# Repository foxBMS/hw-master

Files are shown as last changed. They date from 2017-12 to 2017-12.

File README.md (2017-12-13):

# foxBMS

foxBMS is a free, open and flexible development environment to design battery management systems. It is the first modular open source BMS development platform.

## foxBMS Project Setup
The foxBMS project consists of several repositories.

The foxConda environment. This environment provides all the tools necessary to generate the documentation, compile the code for the MCUs and flash the generated binaries on the MCUs (e.g., Python, git, GCC).

The starting point to get foxBMS is the foxBMS-setup repository (https://github.com/foxBMS/foxbms-setup), which contains the general setup files for the foxBMS project. It includes a setup script (bootstrap.py) which clones all the other needed repositories. The needed documentation will be generated automatically after these repositories have been cloned. The generated documentation is found in the directory ./build. After the bootstrap step, the top project directory (foxBMS-setup) structure looks like this:

 - foxbms-setup <dir>
  - .git <dir> *
  - build <dir>
  - documentation <dir>
  - embedded-software
   - mcu-primary <dir>
   - mcu-secondary <dir>
   - mcu-common <dir>
   - mcu-freertos <dir>
   - mcu-hal <dir>
  - tools <dir>
  - .gitignore <file> *
  - .config.yaml <file> *
  - bootstrap.py <file>
  - build.py <file>
  - CHANGELOG.md <file>
  - LICENSE.md <file>
  - README.md <file>
  - wscript <file>

* Directories and files with starting full stop are hidden in Windows in default configuration. 

There is a help available by running "python bootstrap.py -h".

## foxBMS Repositories

The foxbms-setup repositories have already been described.

foxBMS is made out of two Microcontroller Units (MCU), named primary and secondary. The C code for the primary MCU is found in the repository foxBMS-primary (https://github.com/foxBMS/mcu-primary). The C code for the secondary MCU is found in the repository foxBMS-secondary (https://github.com/foxBMS/mcu-secondary). The C code common to the primary and secondary MCU is found in the repository mcu-common (https://github.com/foxBMS/mcu-common).The Doxygen documentation is generated from these sources into ./build/primary/doxygen/html and ./build/secondary/doxygen/html respectively. The main file is in both cases index.html.

The layout and schematic files for the foxBMS hardware are found in the foxBMS-hardware repository (https://github.com/foxBMS/hardware).

The Hardware Abstraction Layer (hal) for foxBMS is found in the hal-repository (https://github.com/foxBMS/mcu-hal). The real time operating system (FreeRTOS) for foxBMS is found in the FreeRTOS-repository (https://github.com/foxBMS/mcu-freertos).

The tools needed for foxBMS are in the foxBMS-tools-repository (https://github.com/foxBMS/tools.)

The general documentation files for the foxBMS project are found in the foxBMS-documentation repository (https://github.com/foxBMS/documentation). The sphinx documentation is found in foxBMS-documentation/doc/sphinx while the Doxygen documentation configuration is found in foxBMS-documentation/doc/doxygen. The Doxygen documentation itself is found in the software sources of the primary and secondary microcontroller. The general documentation, rendered from the sphinx sources is found in ./build/sphinx/foxBMS-documentation/doc/sphinx/html. The main file is index.html

A generated version of the Sphinx documentation can be found at http://foxbms.readthedocs.io/. It explains the structure of the foxBMS hardware, how to install the foxConda environment and how to use foxConda to compile and flash the sources.

## Building the Sources
For building the software, open a shell and type "python build.py -h". All available build options will be displayed. The top build directory is ./build.

## Cleaning the ./build-Directory
For cleaning instructions open a shell and type "python clean.py -h". All available cleaning options will be displayed.

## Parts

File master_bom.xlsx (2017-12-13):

 | Pos | Populate | Qty | Value | Device | Package | Parts | Description | Farnell | Digikey | Mouser
Resistor
 | 1 | yes | 9 | 0 | R-EU_R0603 | R0603 | R403 R406 R501 R506 R705 R1403 R1404 R1407 R1408 | RESISTOR, European symbol | 2059527
 | 2 | yes | 2 | 1.5k | R-EU_R0603 | R0603 | R701 R702 | RESISTOR, European symbol | 2303156
 | 3 | yes | 12 | 10 | R-EU_R0603 | R0603 | R706 R901 R905 R909 R912 R1001 R1002 R1007 R1008 R1013 R1014 R806 | RESISTOR, European symbol | 2302958
 | 4 | yes | 32 | 10k | R-EU_R0603 | R0603 | R401 R402 R405 R407 R502 R504 R505 R507 R707 R708 R709 R710 R903 R904 R908 R911 R1003 R1004 R1009 R1010 R1015 R1016 R1107 R1108 R1109 R1110 R1111 R1112 R1501 R1502 R803 R805 | RESISTOR, European symbol | 2303192
 | 5 | yes | 1 | 120 | R-EU_R0603 | R0603 | R902 | RESISTOR, European symbol | 2303067
 | 6 | yes | 6 | 130 | R-EU_R0603 | R0603 | R201 R301 R408 R409 R508 R509 | RESISTOR, European symbol | 2059288
 | 7 | yes | 8 | 430 | R-EU_R0603 | R0603 | R907 R910 R1005 R1006 R1011 R1012 R1017 R1018 R804 | RESISTOR, European symbol | 2145386
 | 8 | yes | 1 | 330 | R-EU_R0603 | R0603 | R906 | RESISTOR, European symbol | 2145370
 | 9 | yes | 4 | 27 | R-EU_R0603 | R0603 | R1401 R1402 R1405 R1406 | RESISTOR, European symbol | 2145363
 | 10 | yes | 6 | 47 | R-EU_R0603 | R0603 | R1101 R1102 R1103 R1104 R1105 R1106 | RESISTOR, European symbol | 2145397
 | 11 | yes | 2 | 62 | R-EU_R0603 | R0603 | R801 R802 | RESISTOR, European symbol | 2303039
 | 12 | yes | 4 | 680 | R-EU_R0603 | R0603 | R404 R503 R703 R704 | RESISTOR, European symbol | 2303131
Capacitor
 | 13 | yes | 74 | 100n | C-EUC0603 | C0603 | C202 C206 C208 C301 C306 C308 C401 C404 C405 C406 C407 C408 C409 C410 C411 C412 C413 C415 C416 C417 C418 C419 C420 C421 C422 C424 C425 C430 C502 C503 C504 C506 C507 C508 C509 C510 C513 C601 C602 C703 C706 C707 C1103 C1104 C1105 C1106 C1107 C1402 C1403 C1404 C1405 C1407 C1408 C1409 C1410 C1601 C1602 C1603 C1604 C1801 C1802 C1803 C1804 C1805 C1806 C1807 C2101 C2102 C803 C804 C805 C806 C807 C1501 | CAPACITOR, European symbol | 1828890
 | 14 | yes | 4 | 100n 50V | C-EUC0604 | C0603 | C702 C802 C902 C1102 | CAPACITOR, European symbol | 2346967
 | 15 | yes | 8 | 18p | C-EUC0605 | C0603 | C402 C414 C428 C429 C501 C505 C704 C705 | CAPACITOR, European symbol | 2070403
 | 16 | yes | 6 | 1µ | C-EUC0606 | C0603 | C205 C207 C305 C307 C403 C423 | CAPACITOR, European symbol | 1907343
 | 17 | yes | 3 | 1µ 35V | C-EUC0607 | C0603 | C701 C801 C1101 | CAPACITOR, European symbol | 2346909
 | 18 | yes | 4 | 2.2µ | C-EUC0608 | C0603 | C426 C427 C511 C512 | CAPACITOR, European symbol | 2346961
 | 19 | yes | 7 | 2.2µ 50V | C-EUC0609 | C0805 | C201 C203 C204 C302 C303 C304 C901 | CAPACITOR, European symbol | 2346945
 | 20 | yes | 2 | 4.7µ | C-EUC0610 | C0603 | C1401 C1406 | CAPACITOR, European symbol | 2362098
L
 | 21 | yes | 1 |  | L0805 | 0805 | L401 |  | 2443249
 | 22 | yes | 1 |  | B82789N | B82789N | L801 |  |  |  | 871-B82789C513N2
LED
 | 23 | yes | 2 | Green | LEDCHIP-LED0603 | CHIP-LED0603 | LED402 LED502 | LED | 2099223
 | 24 | yes | 2 | Red | LEDCHIP-LED0603 | CHIP-LED0603 | LED401 LED501 | LED | 2099221
 | 25 | yes | 2 | Orange | LEDCHIP-LED0603 | CHIP-LED0603 | LED201 LED301 | LED | 2099222
XTAL
 | 26 | yes | 2 | 7B-8.000MAAJ-T | 7B-8.000MAAJ-T | MJ | Q401 Q501 | MJ Quarz, 5 x 3.2 x 1.0mm SMD | 2308726
 | 27 | yes | 1 |  | MS3V | MS3V-T1R | Q402 |  | 1539368
Transistor
 | 28 | yes | 2 | BSS84P | BSS84P | SOT23 | T401 T501 | #2245 | 1056526
 | 29 | yes | 1 | BUK964R8-60E | BUK964R8-60E | TO-263AB | T901 | #2797 N-Channel PowerTrench MOSFET 60V, 75A 10.5mOhm | 2254205
 | 30 | yes | 10 | IRLML0100TRPBF | IRLML0100TRPBF | SOT-23 | T701 T801 T902 T903 T1001 T1002 T1003 T1004 T1005 T1006 |  | 1783928
IC
 | 31 | yes | 1 | ADR3425 | ADR3425 | SOT23-6 | IC401 | Micropower, high accuracy, voltage references | 2377039
 | 32 | yes | 2 | ADUM3300 | ADUM3300 | SO-16W | IC1102 IC1103 | Triple-Channel Digital Isolators | 2409432
 | 33 | yes | 1 | ADUM3301 | ADUM3301 | SO-16W | IC702 | Triple-Channel Digital Isolators | 2462515
 | 34 | yes | 3 | ADUM3401 | ADUM3401 | SO16W | IC601 IC1403 IC1406 | Analog Devices Magnetkoppler 4-Kanal | 1274129
 | 35 | yes | 2 | FT231XS-R | FT231XS-R | IC_SMD_SSOP-20 | IC1402 IC1405 | FT231X?-* - FTDI | 2081328
 | 36 | yes | 1 | AT25128B-SSHL-T | AT25128B-SSHL-T | SO8 | IC1501 | SPI bus serial EEPROM | 2345601
 | 37 | yes | 1 | TJA1052IT/5Y | TJA1052IT/5Y | SO16W | IC802 |  | 2400552
Diode
 | 38 | yes | 1 | PESD1CAN | PESD1CAN | SOT-23_NEU | D801 | NXP PESD1CAN CAN bus ESD protection diode | 1510703
 | 39 | yes | 1 | STPS3L60U | STPS3L60U | SMB | D201 | Schottky Diode | 9907769
 | 40 | yes | 2 | MM3Z12VT1G | MM3Z12VT1G | SOD323 | D901 D902 | MM3Z_xVx_T1 Series Zener Diode | 1431191
 | 41 | yes | 6 | CDSOD323-T05 | CDSOD323-T05 | SOD323 | D1101 D1102 D1103 D1104 D1105 D1106 | TVS CDSOD323-T05 | 2341914
 | 42 | yes | 2 | MM3Z4V7ST1G | MM3Z4V7ST1G | SOD323 | D701 D702 | MM3Z_xVx_T1 Series Zener Diode | 2463512
 | 43 | no | 6 | GF1B | GF1B | SMA-DO214AC | D1001 D1002 D1003 D1004 D1005 D1006 | DIODE | 1467477
MCU
 | 44 | yes | 1 | STM32F429IIT6 | STM32F429IIT6 | LQFP176 | IC402 | ARM 32-bit Cortex™-M3 CPU |  | 497-14054-ND
 | 45 | yes | 1 | STM32F429VIT6 | STM32F429VGT6 | LQFP100 | IC501 | ARM 32-bit Cortex™-M3 CPU | 2393659
Regulator
 | 46 | yes | 1 | KA7805ERTF | KA7805ERTF | TO252 | IC801 | Positive VOLTAGE REGULATOR | 2102585
 | 47 | yes | 2 | UA78L05CPK | UA78L05CPK | SOT89 | IC701 IC1101 | POSITOIV-VOLTAGE REGULATORS | 2112604
 | 48 | yes | 2 | LM1085-3.3 | LM1085-3.3 | TO-263-3L | IC201 IC301 | National Semiconductor LM1085IS-5 3A Low Dropout Positive Regulators | 1469039
 | 49 | yes | 1 | LM317MSTT3 | LM317MSTT3 | SOT223 | IC901 | 500 mA Adjustable Output Positive Voltage Regulator | 1703412
Opto
 | 50 | yes | 6 | AQV252G2SX | AQV252G2SX | SOP06 | IC1001 IC1002 IC1003 IC1004 IC1005 IC1006 |  |  | 255-3594-1-ND
 | 51 | yes | 5 | CPC1008N | CPC1008N | SOP4 | IC803 IC902 IC903 IC904 IC905 | CLARE - Single-Pol, Normally Open 4-Pin SOP OptoMOS Relay, 150mA load current | 1653755
Misc
 | 52 | yes | 1 | SMTU 1225-1-LF | SMTU 1225-1-LF | CR1225_SMD | BATT | #2833 | 1216353
 | 53 | yes | 2 | MC32598 | MC32598 | Mini-USB AB | X1401 X1402 | MINI USB-B Conector | 1696539
 | 54 | yes | 2 | IP4220CZ6 | IP4220CZ6 | TSOP-6 | IC1401 IC1404 |  | 1506629
 | 55 | yes | 1 | IS42S16400J-7TLI | IS42S16400J-7TLI | TSOP-54 | IC1801 |  | 2253831
 | 56 | yes | 2 | KMR211G | KMR211G | KMR211G | S401 S501 | #228 |  | 401-1426-1-ND
 | 57 | yes | 6 | 4,0A_UMT | 4,0A_UMT | F_SMD_11,00MMX3,00MMX3,00MM_(UMT)_R_SCHURTER_REV01 | F1001 F1002 F1003 F1004 F1005 F1006 | UMT-Serie - Schurter Electronic Components |  | 486-1253-ND | 693-3403.0172.11
 | 58 | yes | 1 | 2A | Littelfuse 452 | NANO2 | F201 | 452 Serie Littelfuse | 2383284
 | 59 | yes | 1 | TISP4040H1BJR-S | TISP4040H1BJR-S | SMBJ | T201 | TVS Thyristor |  | TISP4040H1BJR-SCT-ND
Connector SMD
 | 60 | yes | 2 | FTS-110-01-L-DV | FTS-110-01-L-DV | FTS-110-01-L-DV | X403 X502 | SAMTEC connector, #537 | 1667733
Connector THD
 | 61 | yes | 1 | HEADER_POS16_43045-1599 | HEADER_POS16_43045-1600 | 43045-1600 | X1601 | Molex - Micro-Fit 3.0 Series connector, 3.00mm (0.118) pitch header, 16 positions." | 9961380
 | 62 | yes | 1 | HEADER_POS2_43045-0199 | HEADER_POS2_43045-0200 | 43045-0200 | X901 | Molex - Micro-Fit 3.0 Series connector, 3.00mm (0.118) pitch header, 2 positions." | 1012251
 | 63 | yes | 8 | HEADER_POS4_43045-0400 | HEADER_POS4_43045-0401 | 43045-0400 | X701 X801 X1201 X1202 X1203 X1204 X1205 X1206 | Molex - Micro-Fit 3.0 Series connector, 3.00mm (0.118) pitch header, 4 positions." | 9733019
 | 64 | yes | 1 | HEADER_POS6_43045-0599 | HEADER_POS6_43045-0600 | 43045-0600 | X201 | Molex - Micro-Fit 3.0 Series connector, 3.00mm (0.118) pitch header, 6 positions." | 1012252
 | 65 | yes | 1 | MA03-0 | MA03-1 | MA03-1 | X401 | 3Pins | 2505045
 | 66 | yes | 1 |  |  |  | SV901 | 8 Header | 1668094
 | 67 | yes | 3 | MA04-1 | MA04-2 | MA04-2 | SV1601 SV1603 SV2101 | 8 Pins | 2025250
 | 68 | yes | 1 | MA06-1 | MA06-2 | MA06-2 | SV501 | 12 Pins | 2025252
 | 69 | yes | 2 | MA08-1 | MA08-2 | MA08-2 | SV1602 SV1604 | 16 Pins | 2025254
 | 70 | no | 1 | MA02-0 | MA02-0 | MA02-0 | X902 | 1 Pins | 2505044
 | 71 | yes | 2 | MA02-1 | MA02-1 | MA02-1 | X402 X501 | 2 Pins | 2505044
 | 72 | yes | 2 | PINHD-2X11 | PINHD-2X12 | 2X12 | JP2201 JP2202 | 24 Header | 1804783 | SAM1088-12-ND
DC/DC THD
 | 73 | yes | 1 | MURATA_NCS6_SINGLE | MURATA_NCS6_SINGLE | NCS6S1205C | IC202 |  |  | 580-NCS6S1205C
 | 74 | yes | 1 | RECOM-RS2405SZ | RECOM-RS2405SZ | RS-2405SZ/H3 | IC302 |  |  | 919-RS-2405SZ/H3

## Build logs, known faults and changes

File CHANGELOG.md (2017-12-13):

# foxBMS Change Log

## V1.0.2

- replaced ADuM14XX isolators by ADuM34XX

## V1.0.1

- added fuse protection on power supply input

## V1.0.0

- initial release

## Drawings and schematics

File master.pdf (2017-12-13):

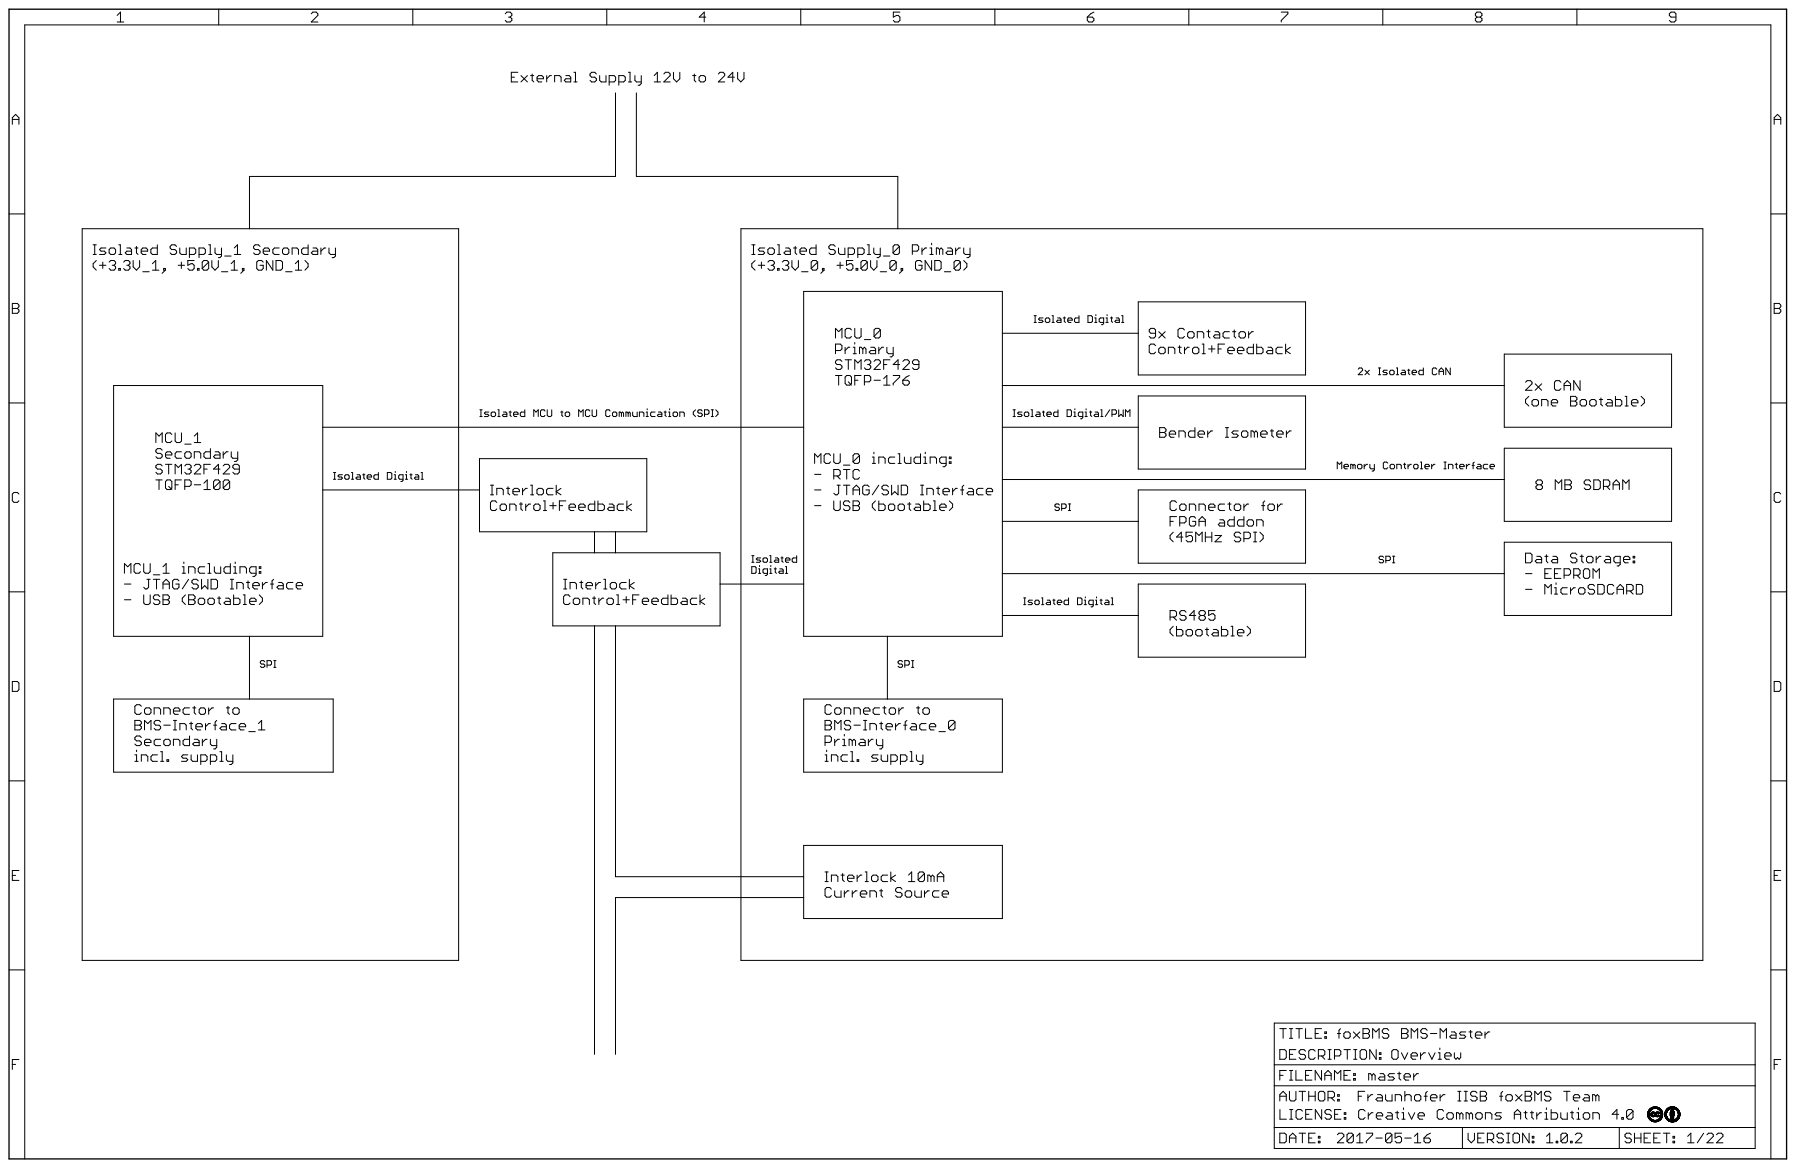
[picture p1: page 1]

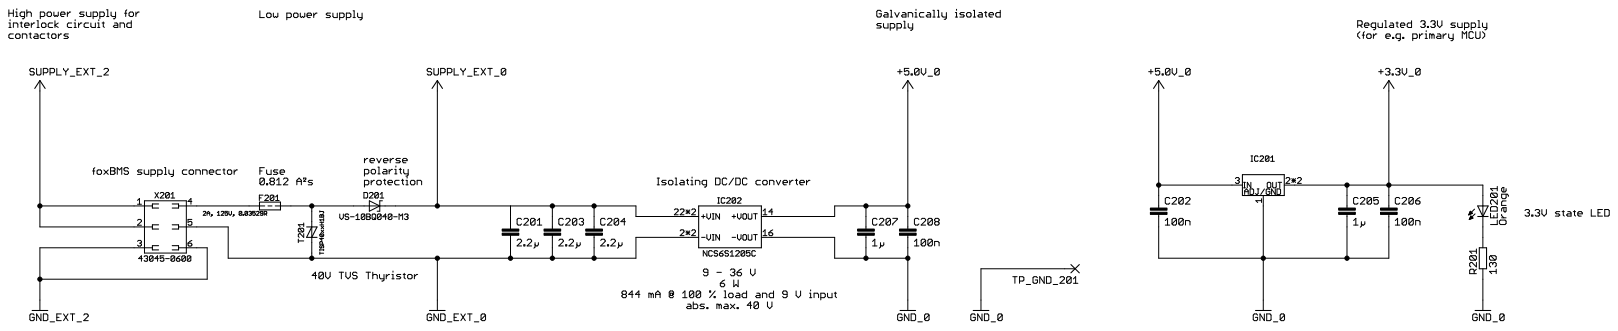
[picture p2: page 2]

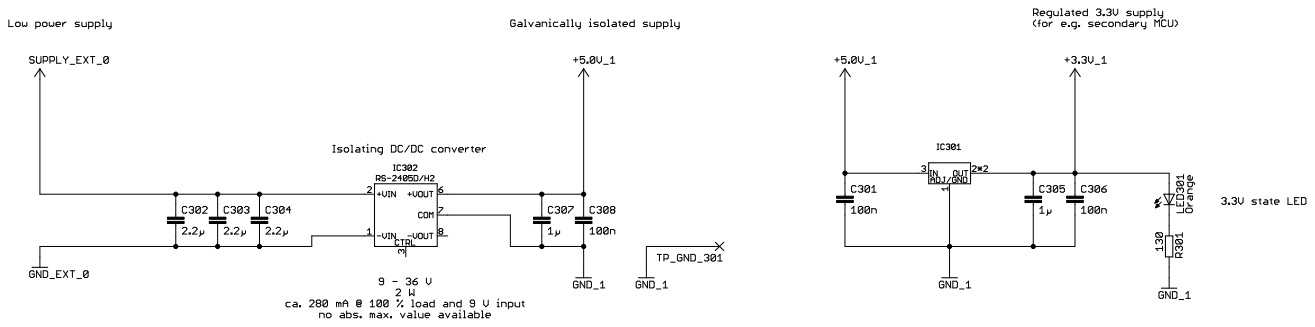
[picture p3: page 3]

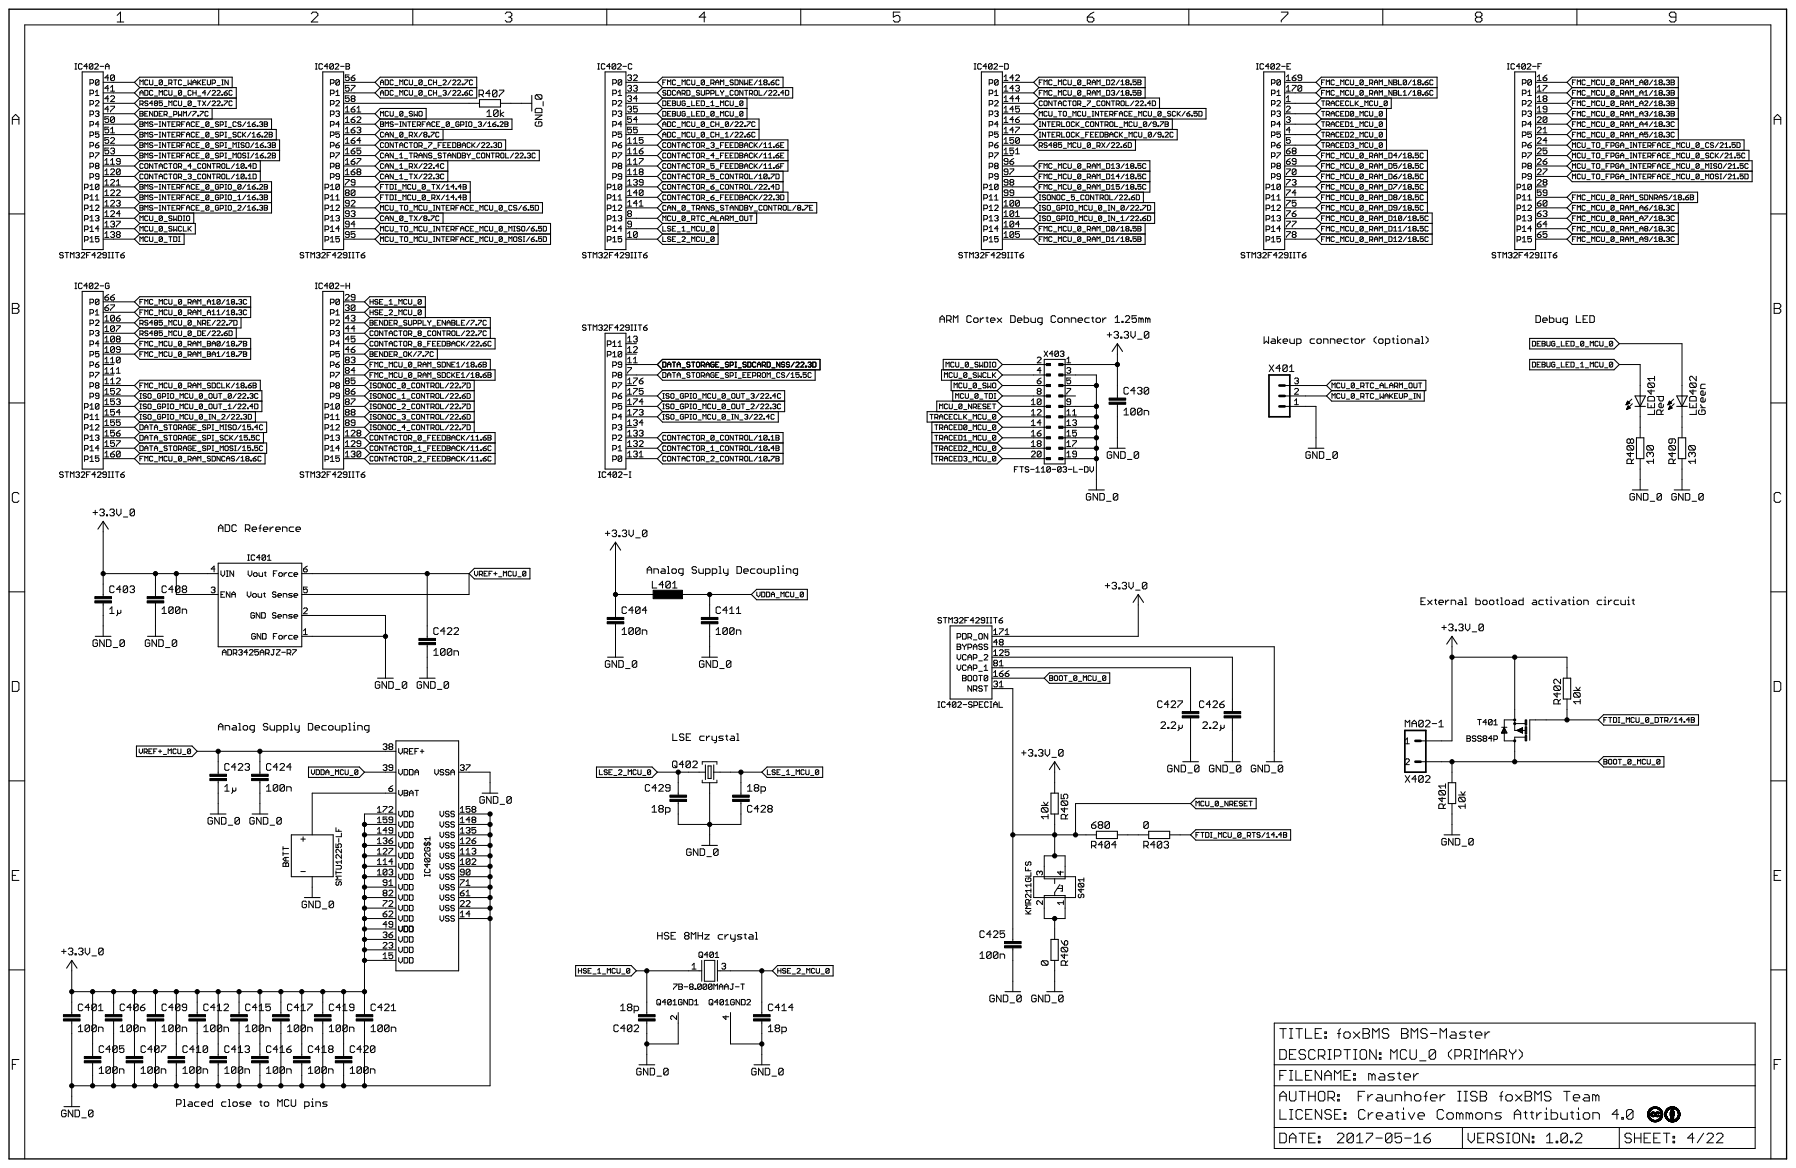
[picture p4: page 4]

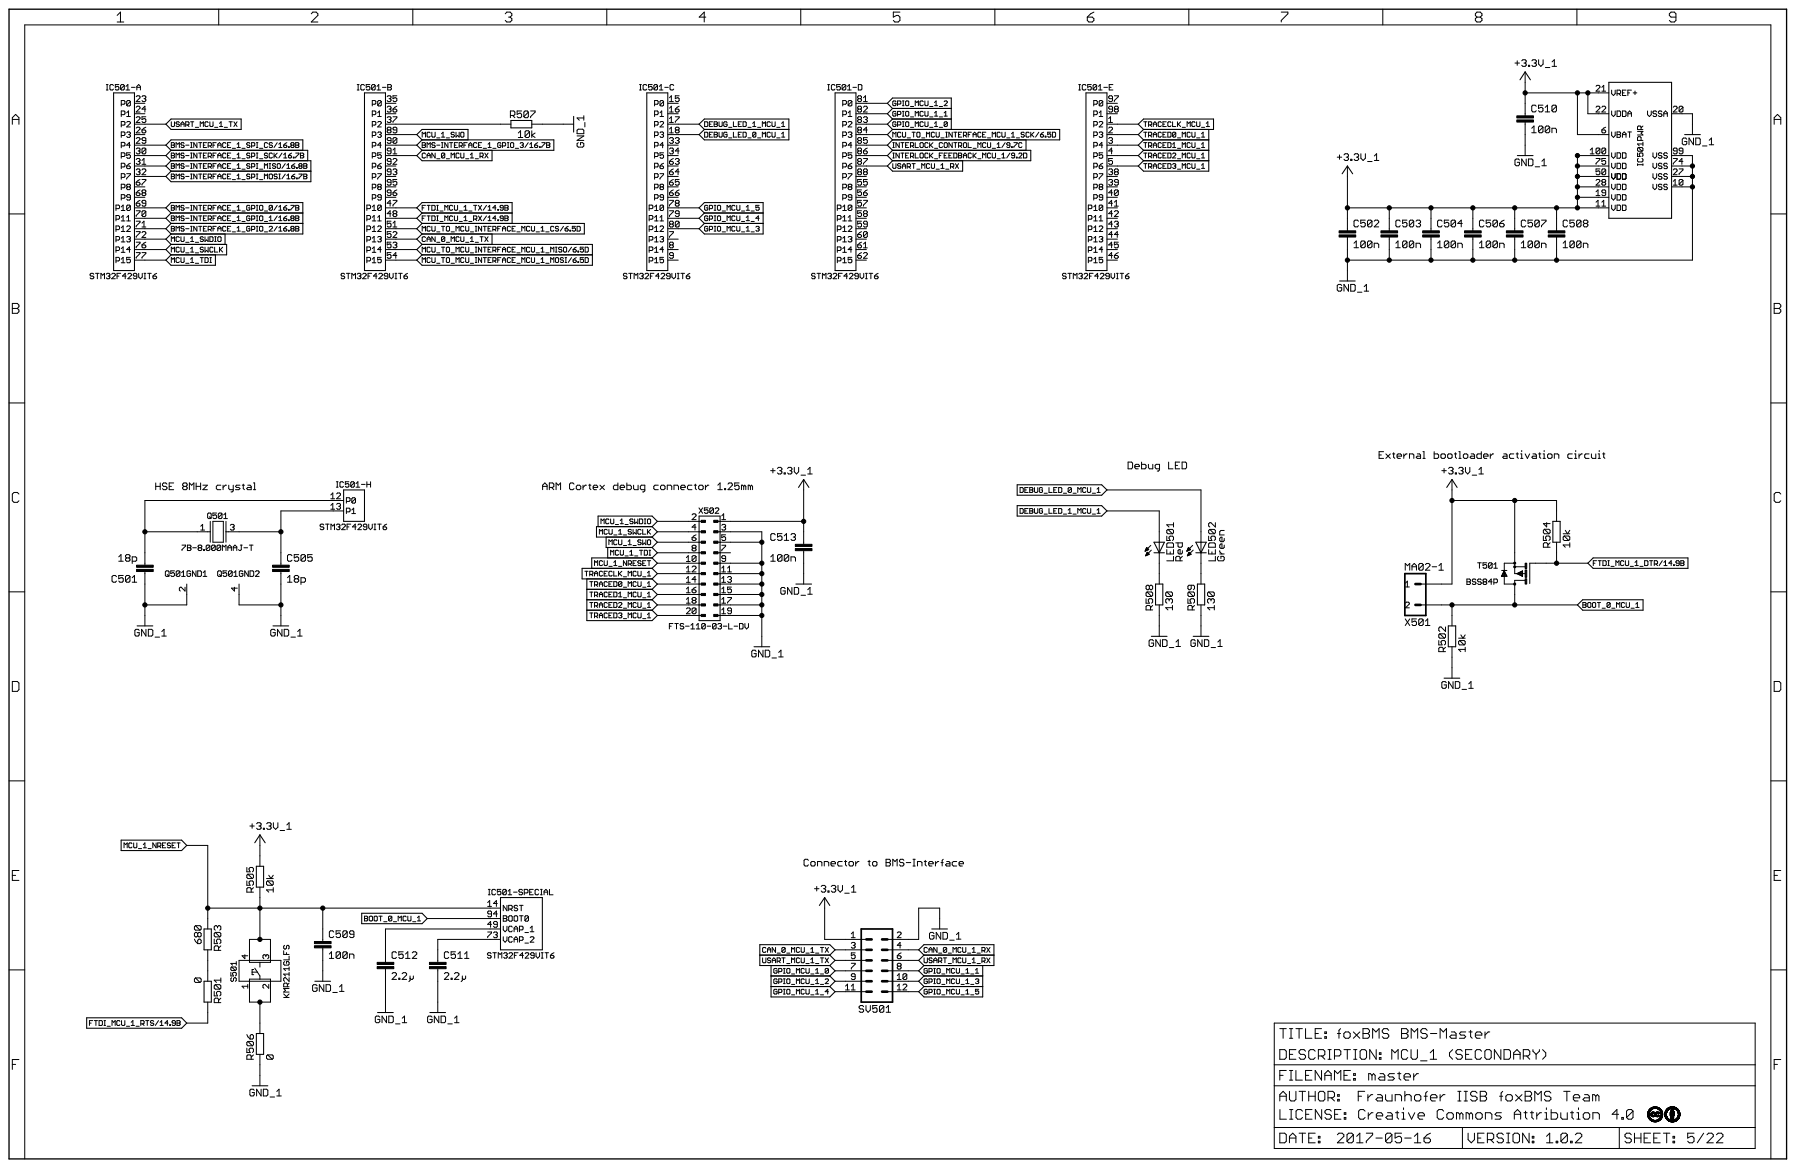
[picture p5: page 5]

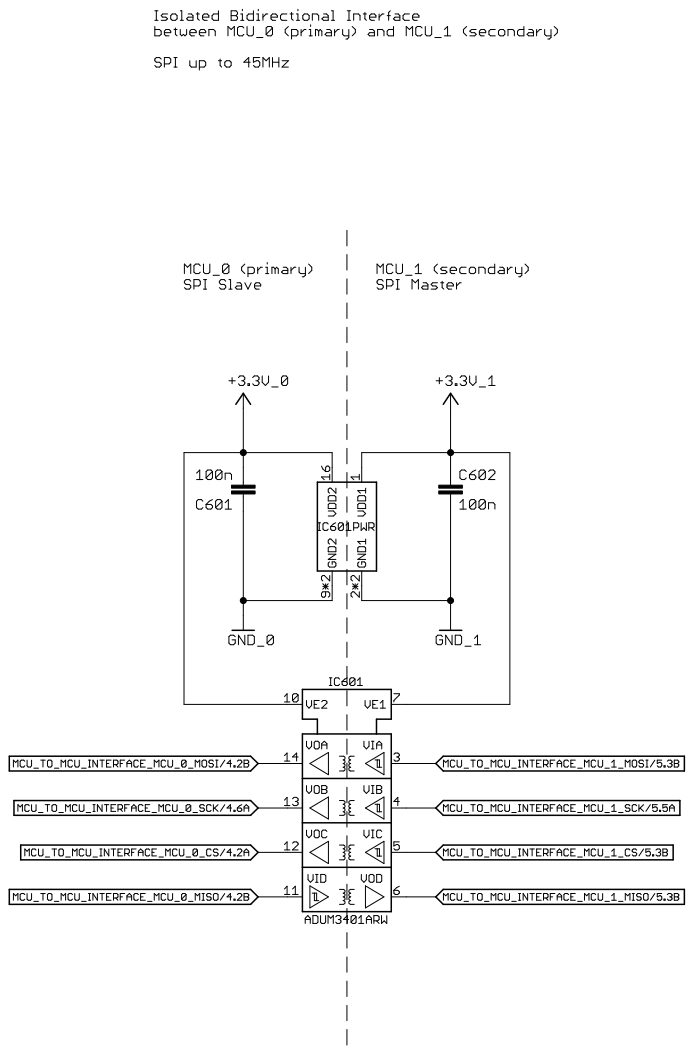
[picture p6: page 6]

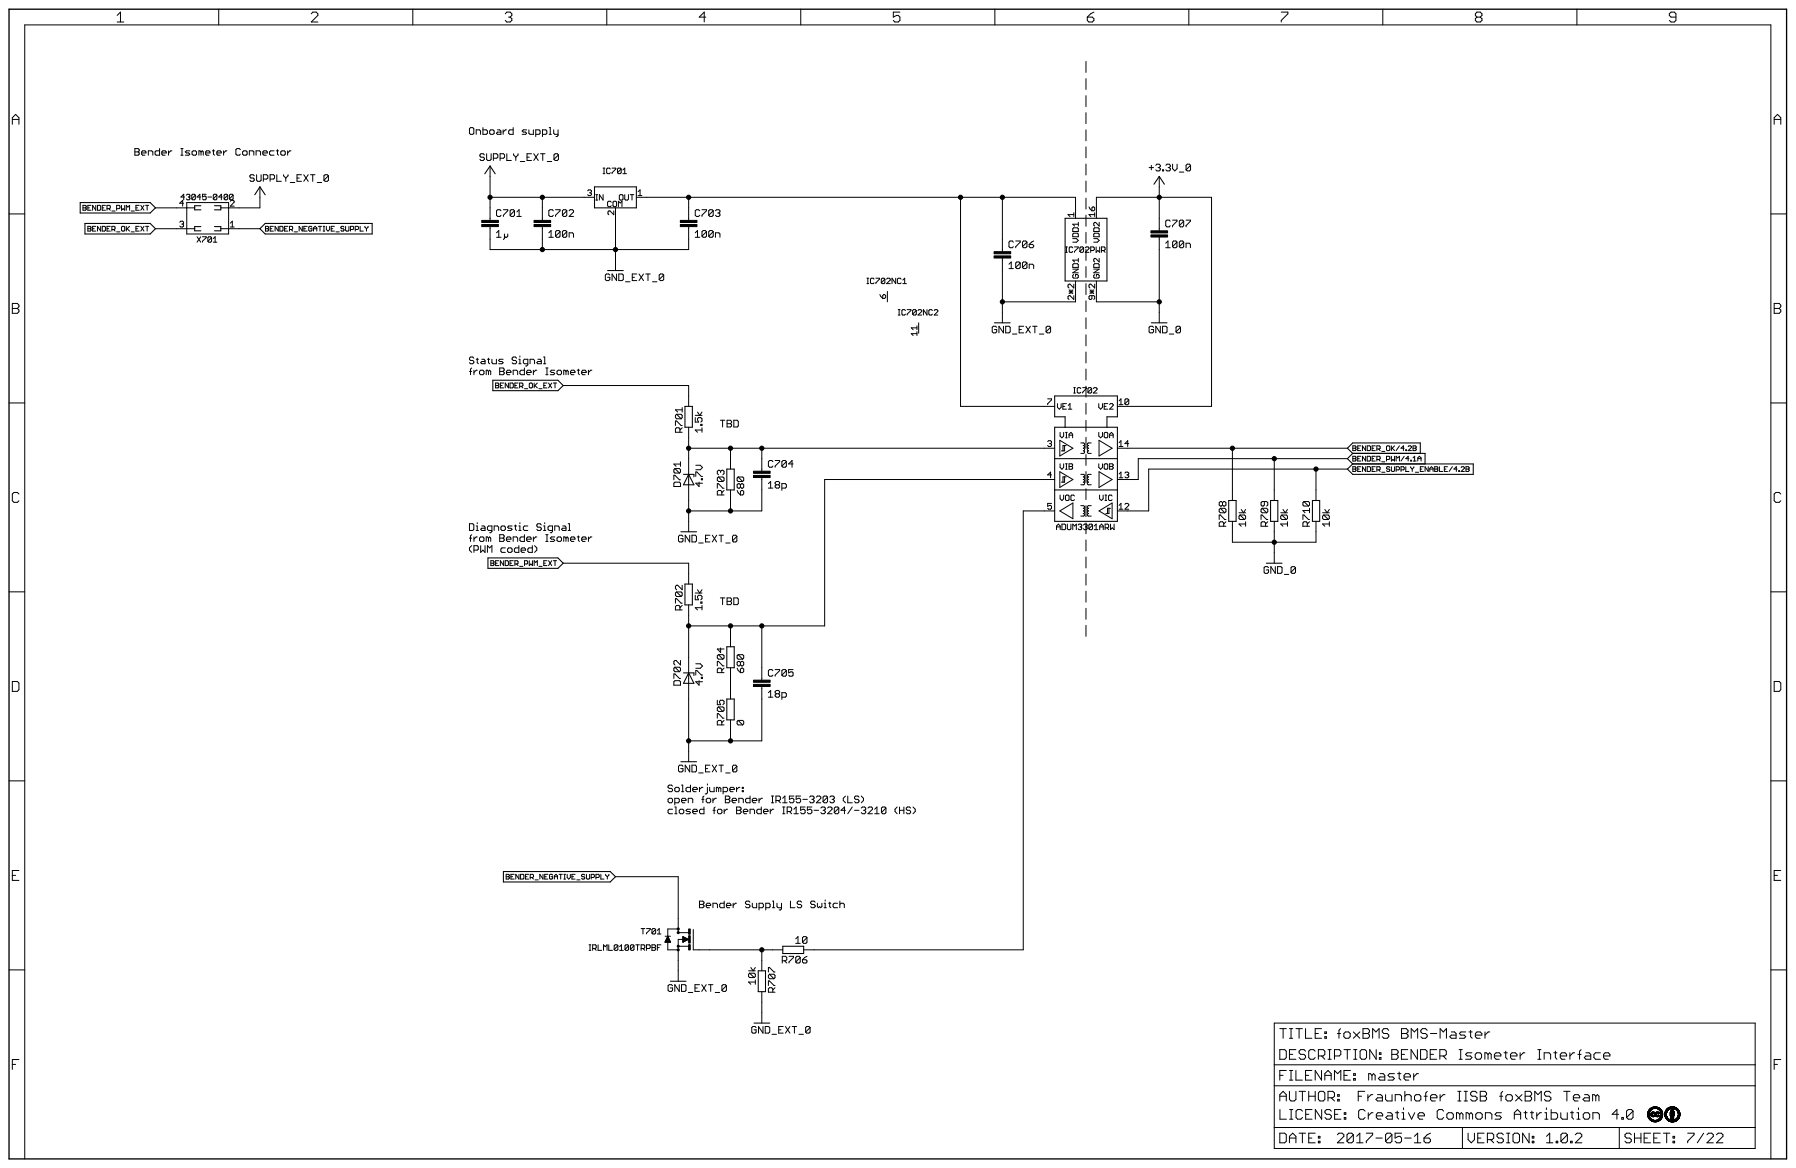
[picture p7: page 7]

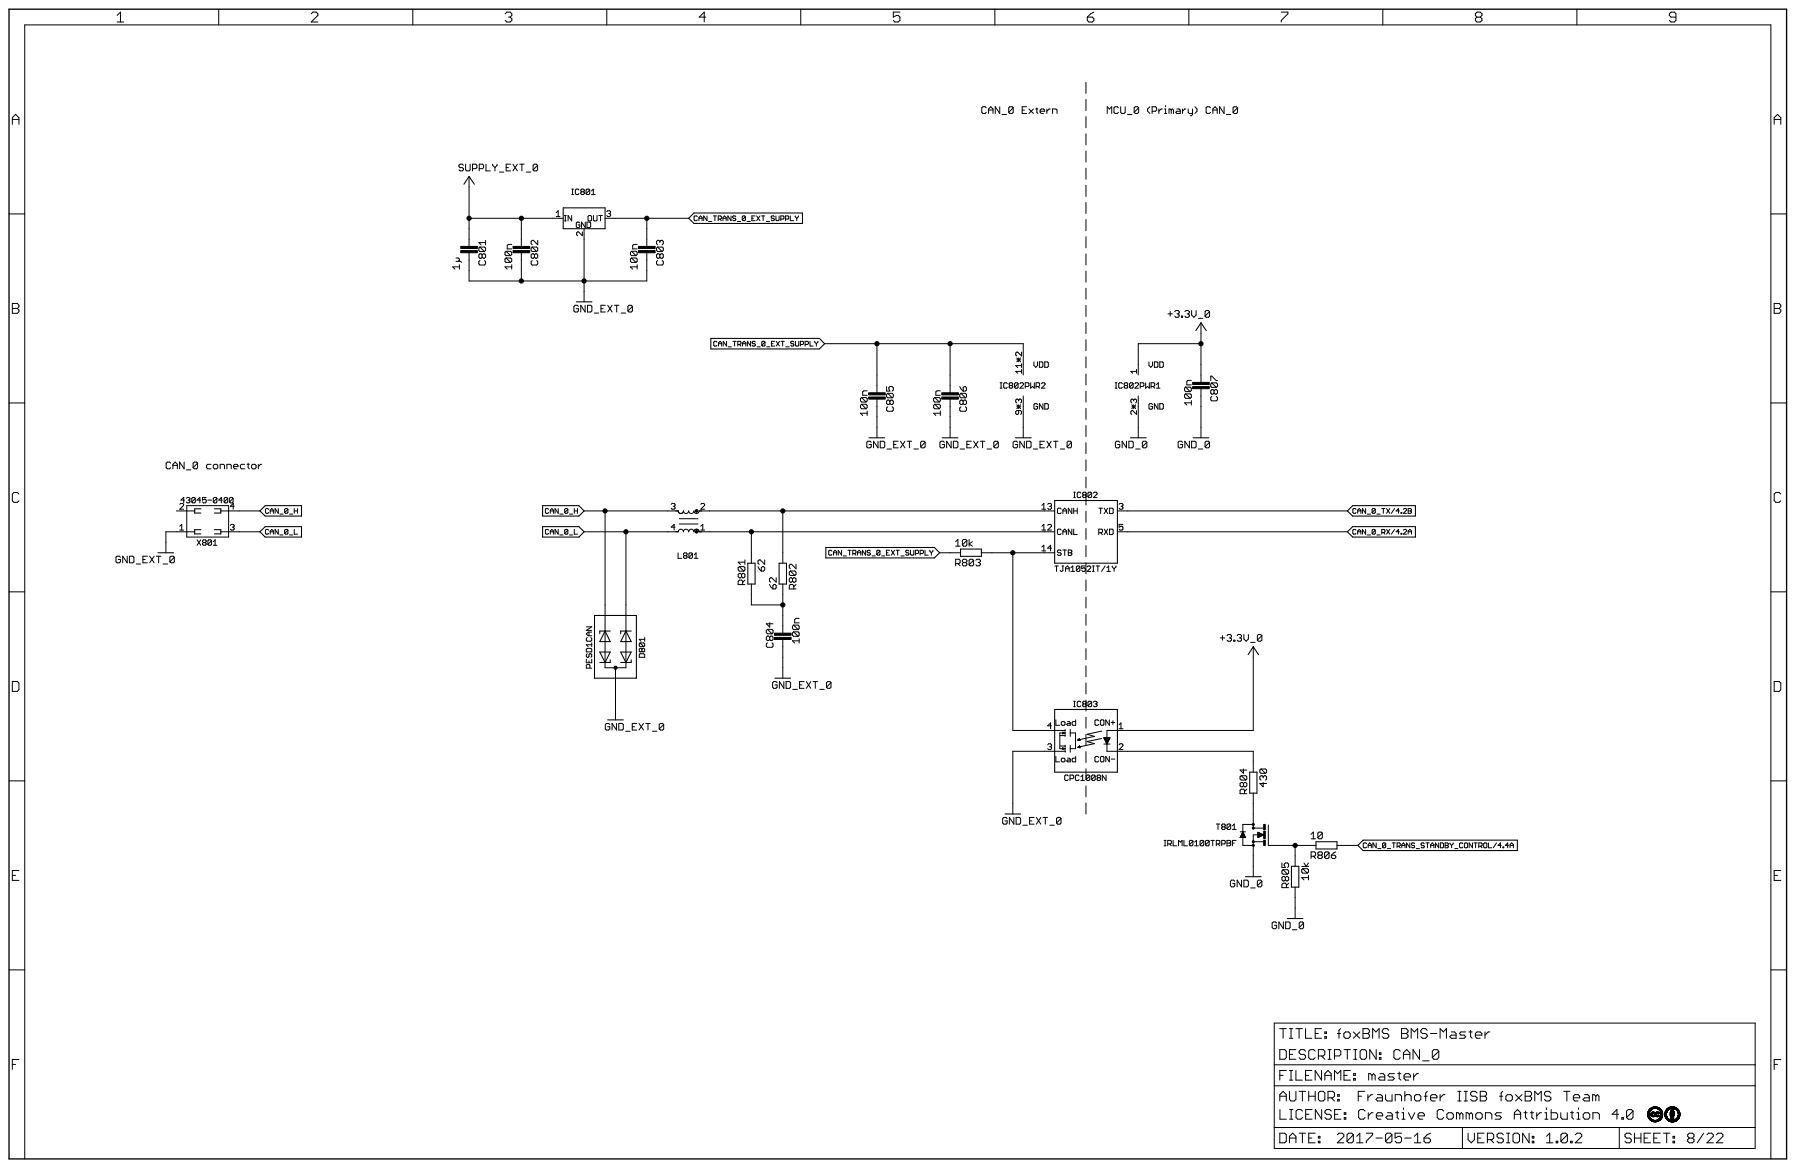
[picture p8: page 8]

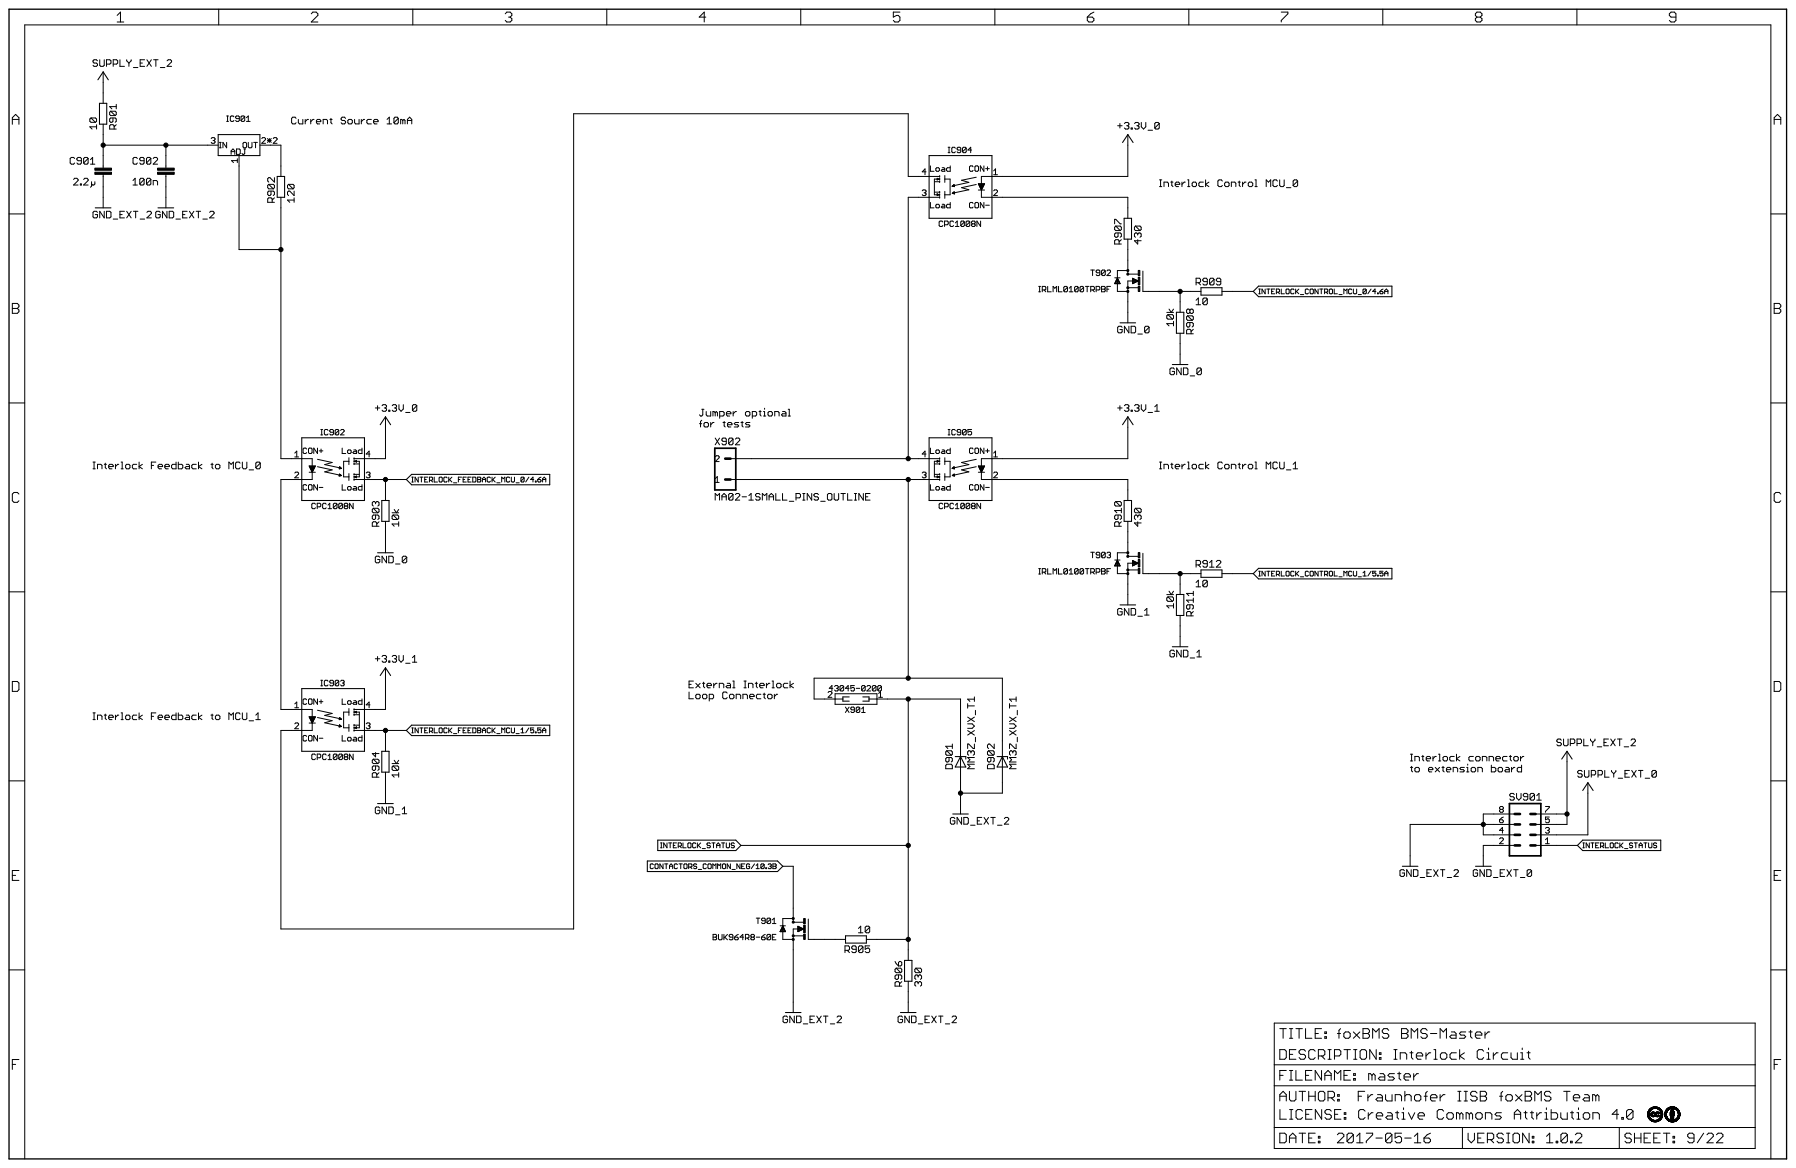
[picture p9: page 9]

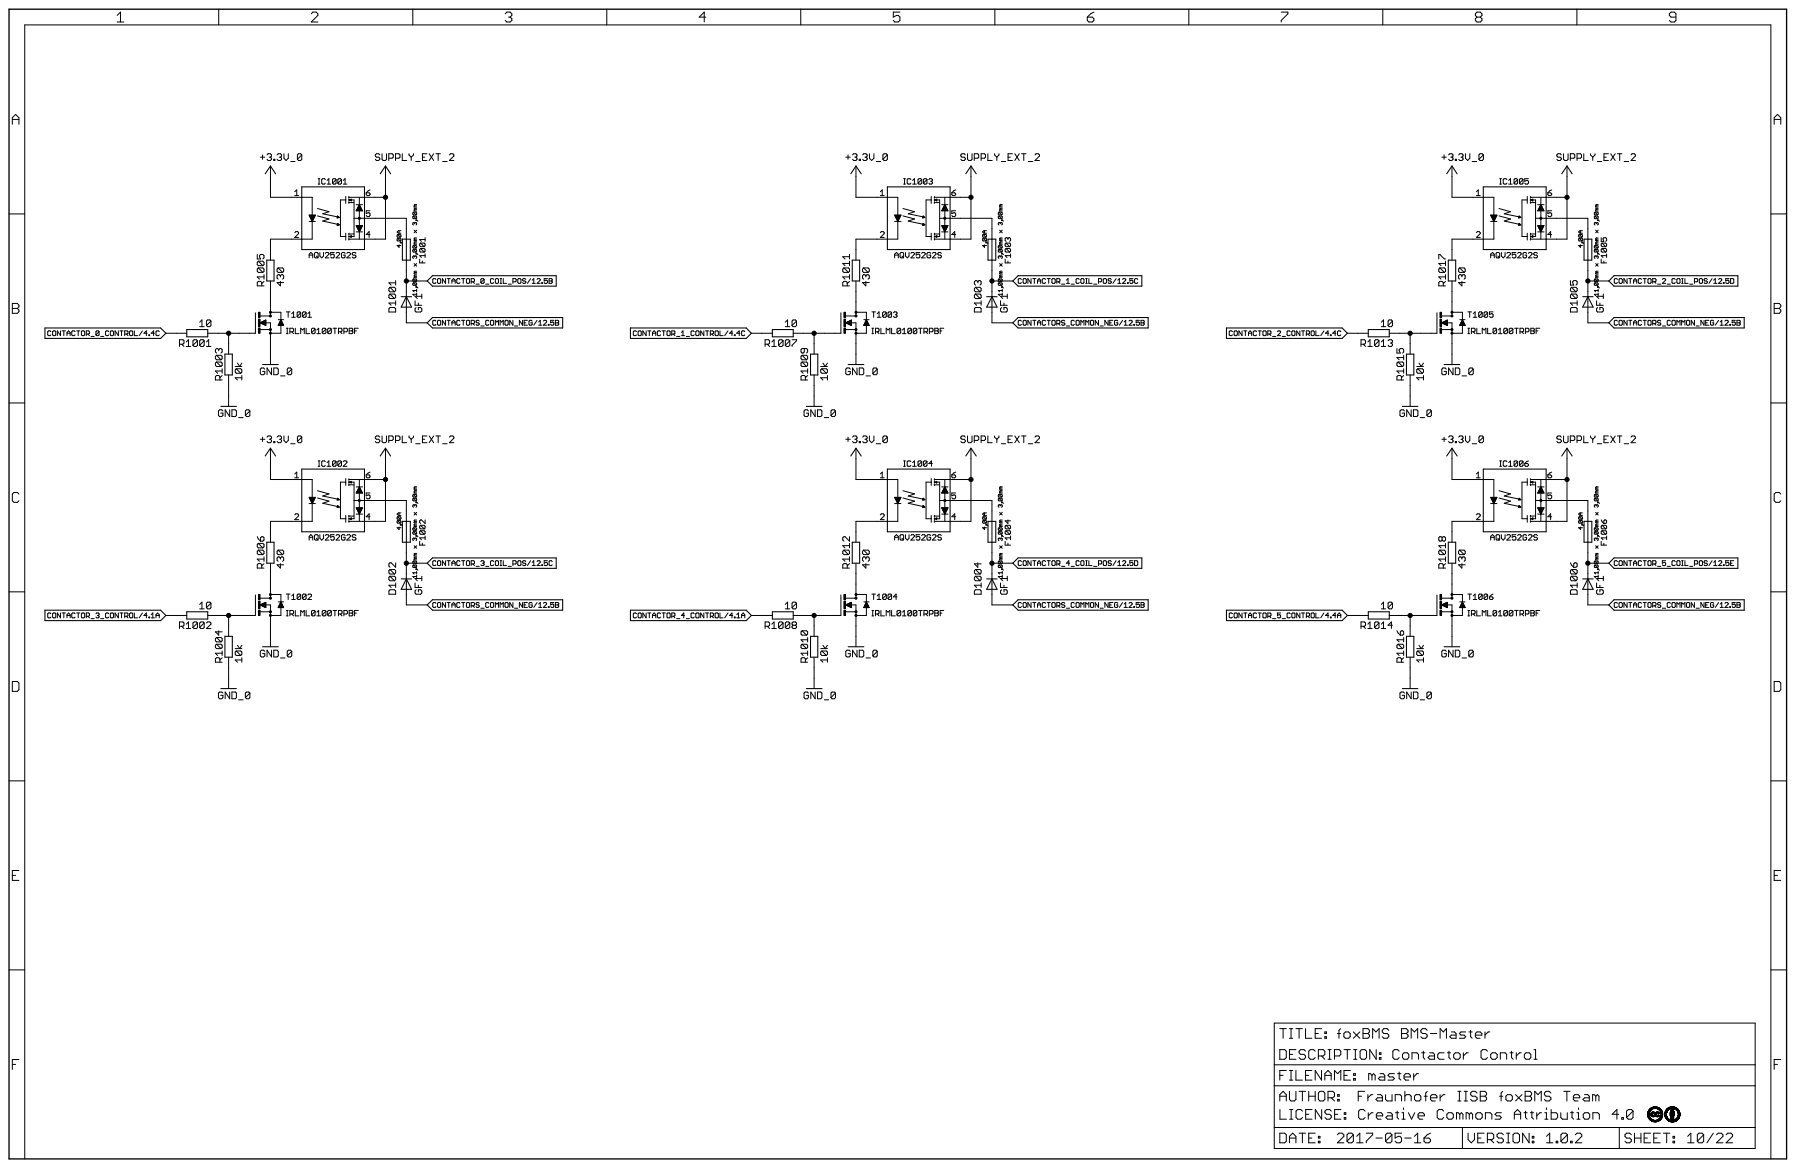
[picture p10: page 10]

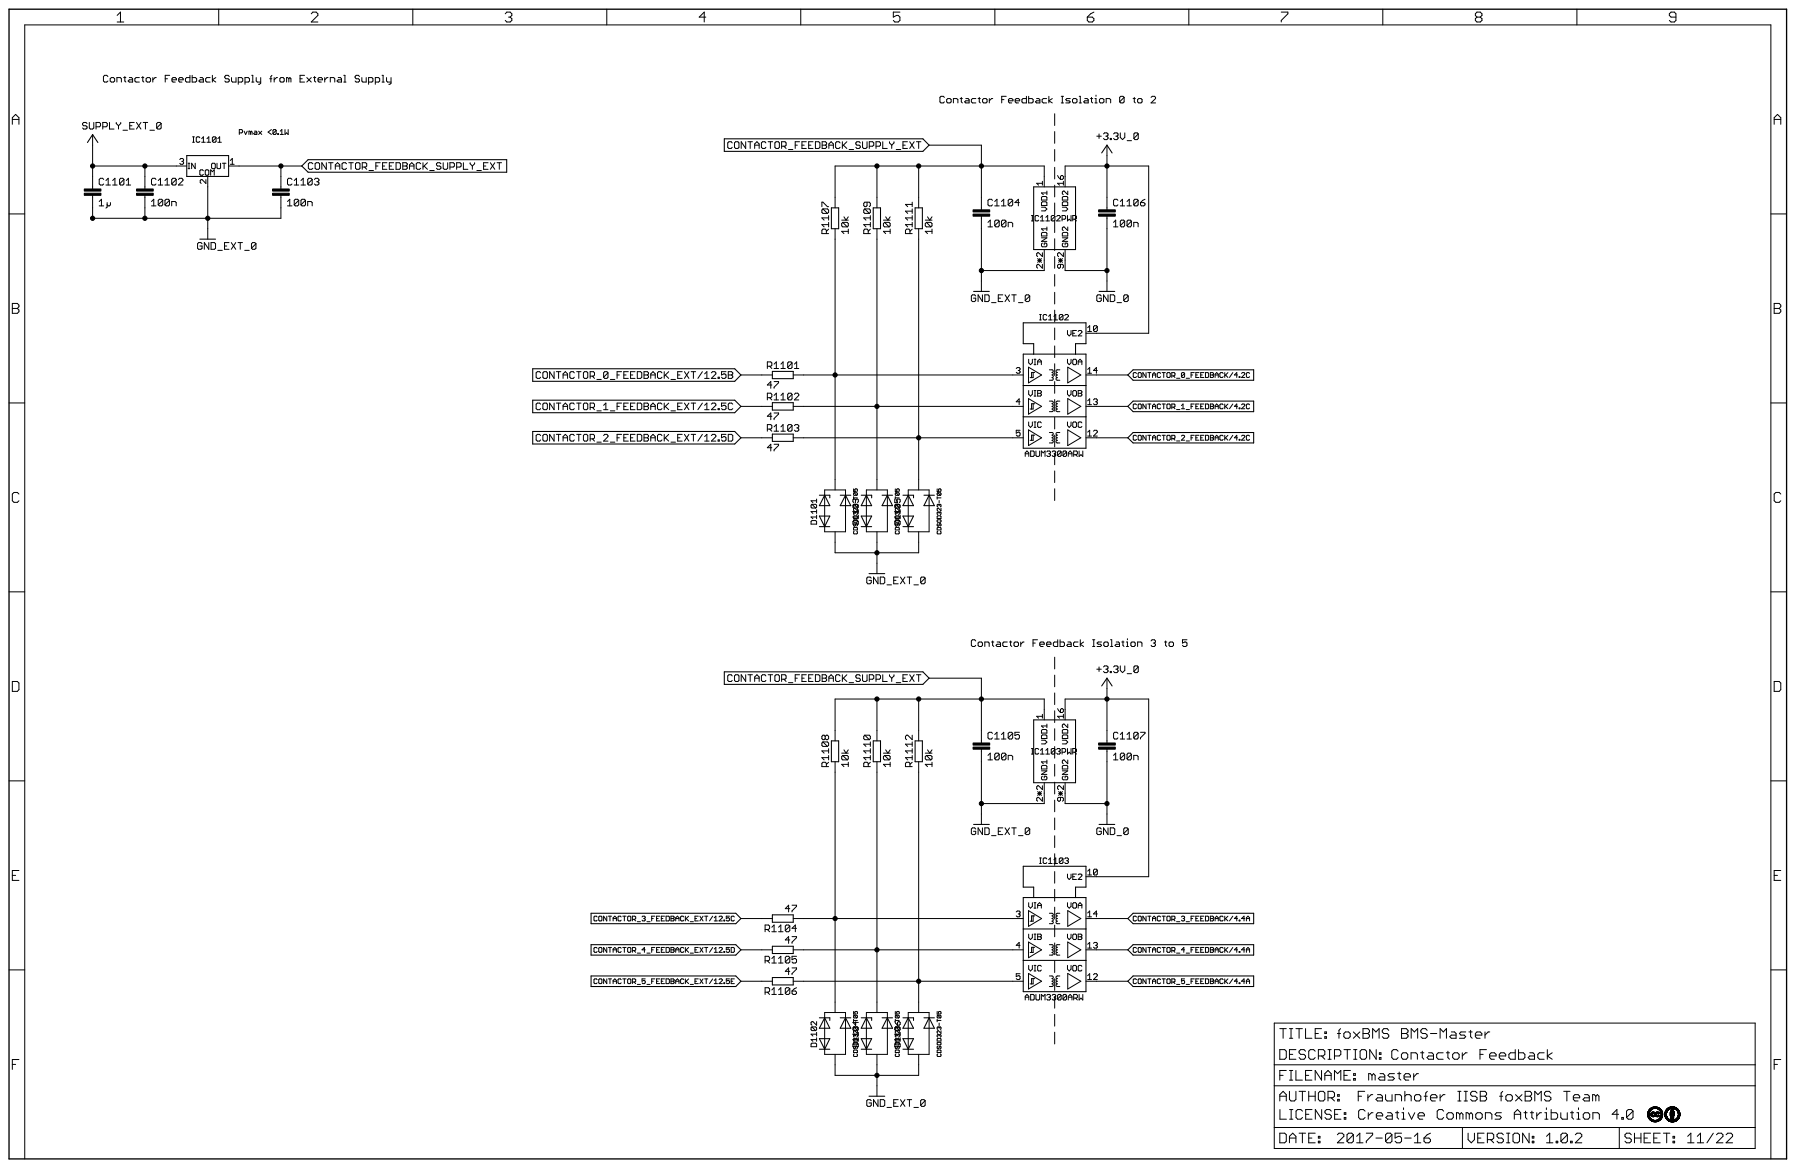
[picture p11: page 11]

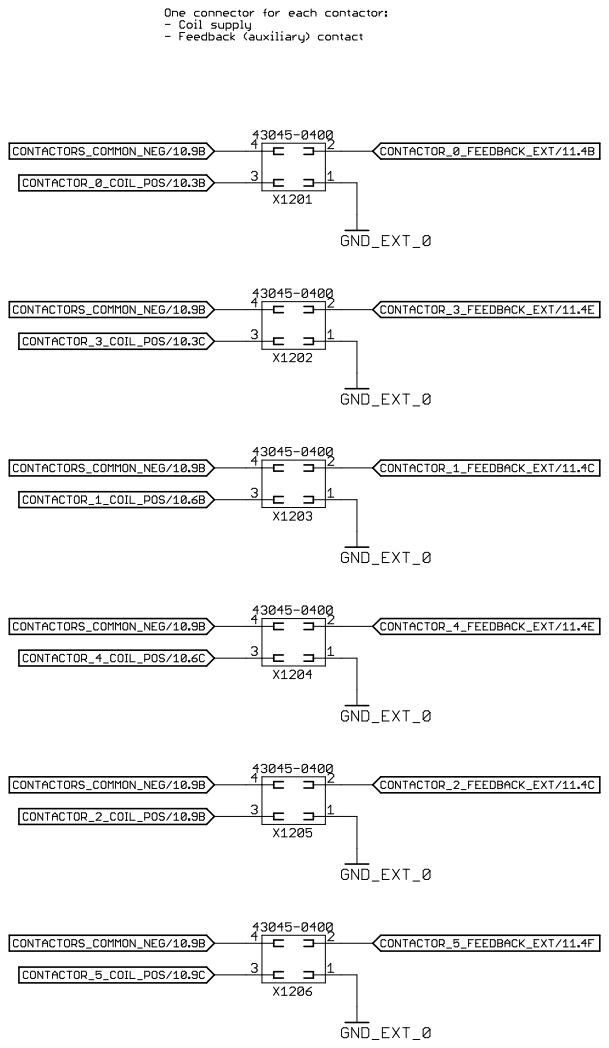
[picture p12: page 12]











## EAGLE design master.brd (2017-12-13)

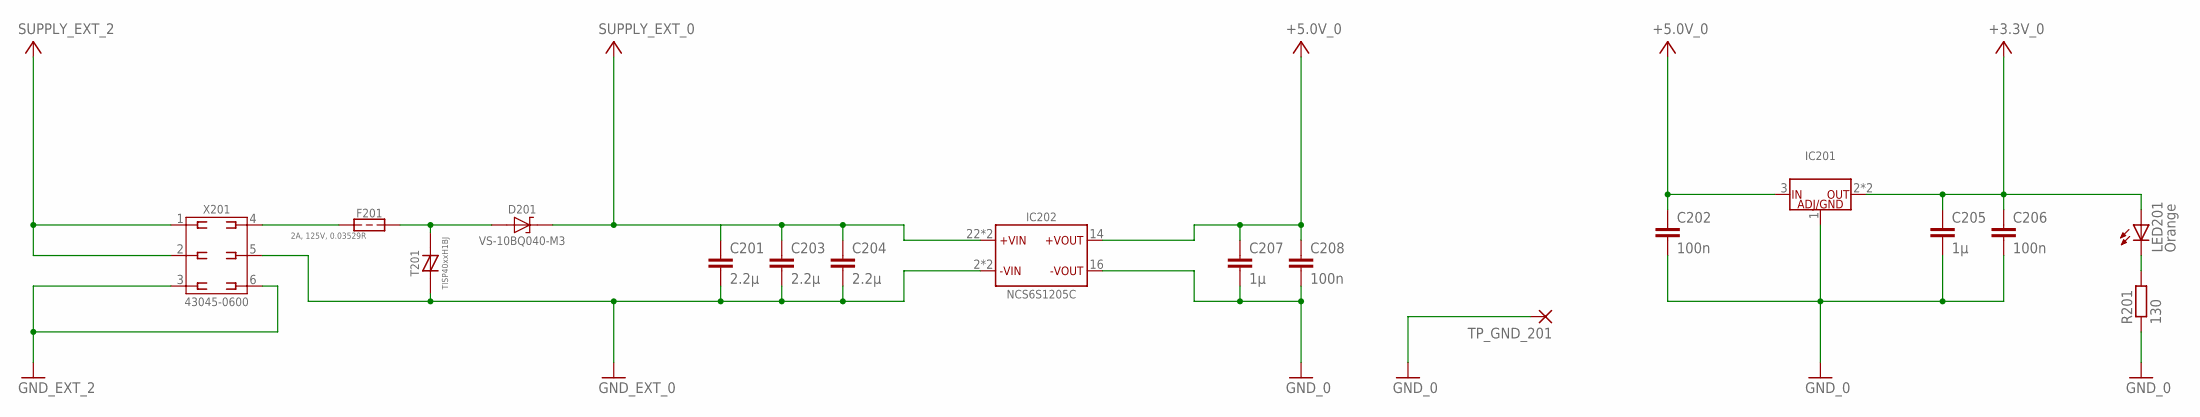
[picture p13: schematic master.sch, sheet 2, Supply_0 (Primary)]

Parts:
C201, C203, C204: 2.2µ; C0805
C202, C206, C208: 100n; C0603
C205, C207: 1µ; C0603
D201: VS-10BQ040-M3; D_SMD_SMB_(DO-214AA)_R_VISHAY_REV01
F201: 0,500A_LITTELFUSE_4482A; 448_SERIES_LITTELFUSE
IC201: LM1085IS-5.0/NOPB; IC_SMD_TO-263-3_(KTT0003B)_R_TI_REV01
IC202: MURATA_NCS6S1205C; IC_TH_32,00MMX20,00MMX10,00MM_(7-PIN)_R_MURATA_REV01
LED201: Orange; CHIP-LED0603
R201: 130; R0603
T201: TISP40XXH1BJ; TVS_THYRISTOR
TP_GND_201: 1,6/0,8
X201: 43045-0600_MOLEX_6PIN; X_TH_MOLEX_43045-0600_R_REV01

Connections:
+3.3V_0: C205.1, C206.1, IC201.2 (OUT), IC201.4 (OUT), LED201.A; also elsewhere on the board
+5.0V_0: C202.1, C207.1, C208.1, IC201.3 (IN), IC202.14 (+VOUT); also elsewhere on the board
GND_0: C202.2, C205.2, C206.2, C207.2, C208.2, IC201.1 (ADJ/GND), IC202.16 (-VOUT), R201.1, TP_GND_201.1; also elsewhere on the board
GND_EXT_0: C201.2, C203.2, C204.2, IC202.2 (-VIN), IC202.3 (-VIN), T201.C (T), X201.5; also elsewhere on the board
GND_EXT_2: X201.3, X201.6; also elsewhere on the board
unnamed: LED201.C, R201.2
unnamed: D201.A, F201.P$2, T201.A (R)
unnamed: F201.P$1, X201.4
SUPPLY_EXT_0: C201.1, C203.1, C204.1, D201.C, IC202.22 (+VIN), IC202.23 (+VIN); also elsewhere on the board
SUPPLY_EXT_2: X201.1, X201.2; also elsewhere on the board

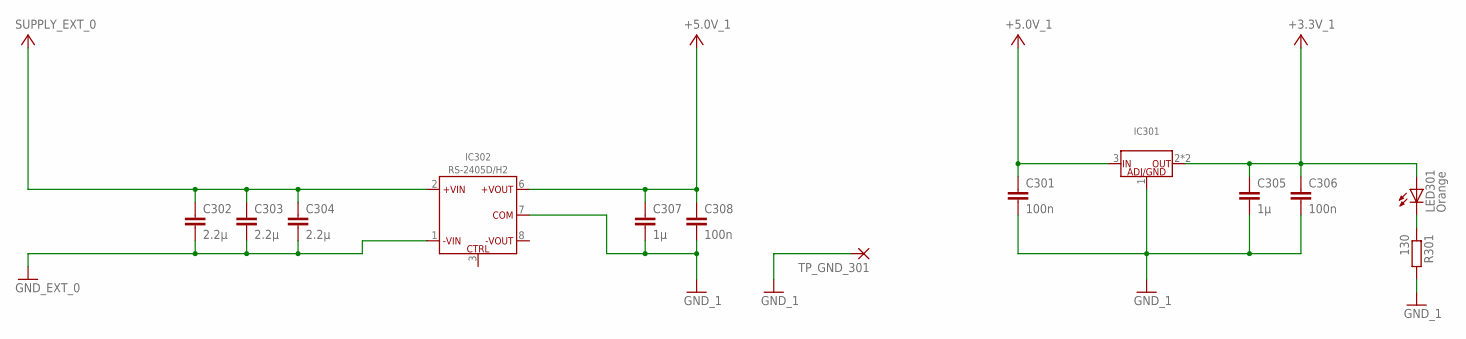
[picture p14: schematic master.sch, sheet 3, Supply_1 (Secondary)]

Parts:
C301, C306, C308: 100n; C0603
C302, C303, C304: 2.2µ; C0805
C305, C307: 1µ; C0603
IC301: LM1085IS-5.0/NOPB; IC_SMD_TO-263-3_(KTT0003B)_R_TI_REV01
IC302: RS-2405D/H2; IC_TH_SIP8_R_RECOM_REV01
LED301: Orange; CHIP-LED0603
R301: 130; R0603
TP_GND_301: 1,6/0,8

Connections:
+3.3V_1: C305.1, C306.1, IC301.2 (OUT), IC301.4 (OUT), LED301.A; also elsewhere on the board
+5.0V_1: C301.1, C307.1, C308.1, IC301.3 (IN), IC302.6 (+VOUT); also elsewhere on the board
GND_1: C301.2, C305.2, C306.2, C307.2, C308.2, IC301.1 (ADJ/GND), IC302.7 (COM), R301.2, TP_GND_301.1; also elsewhere on the board
GND_EXT_0: C302.2, C303.2, C304.2, IC302.1 (-VIN); also elsewhere on the board
unnamed: LED301.C, R301.1
SUPPLY_EXT_0: C302.1, C303.1, C304.1, IC302.2 (+VIN); also elsewhere on the board

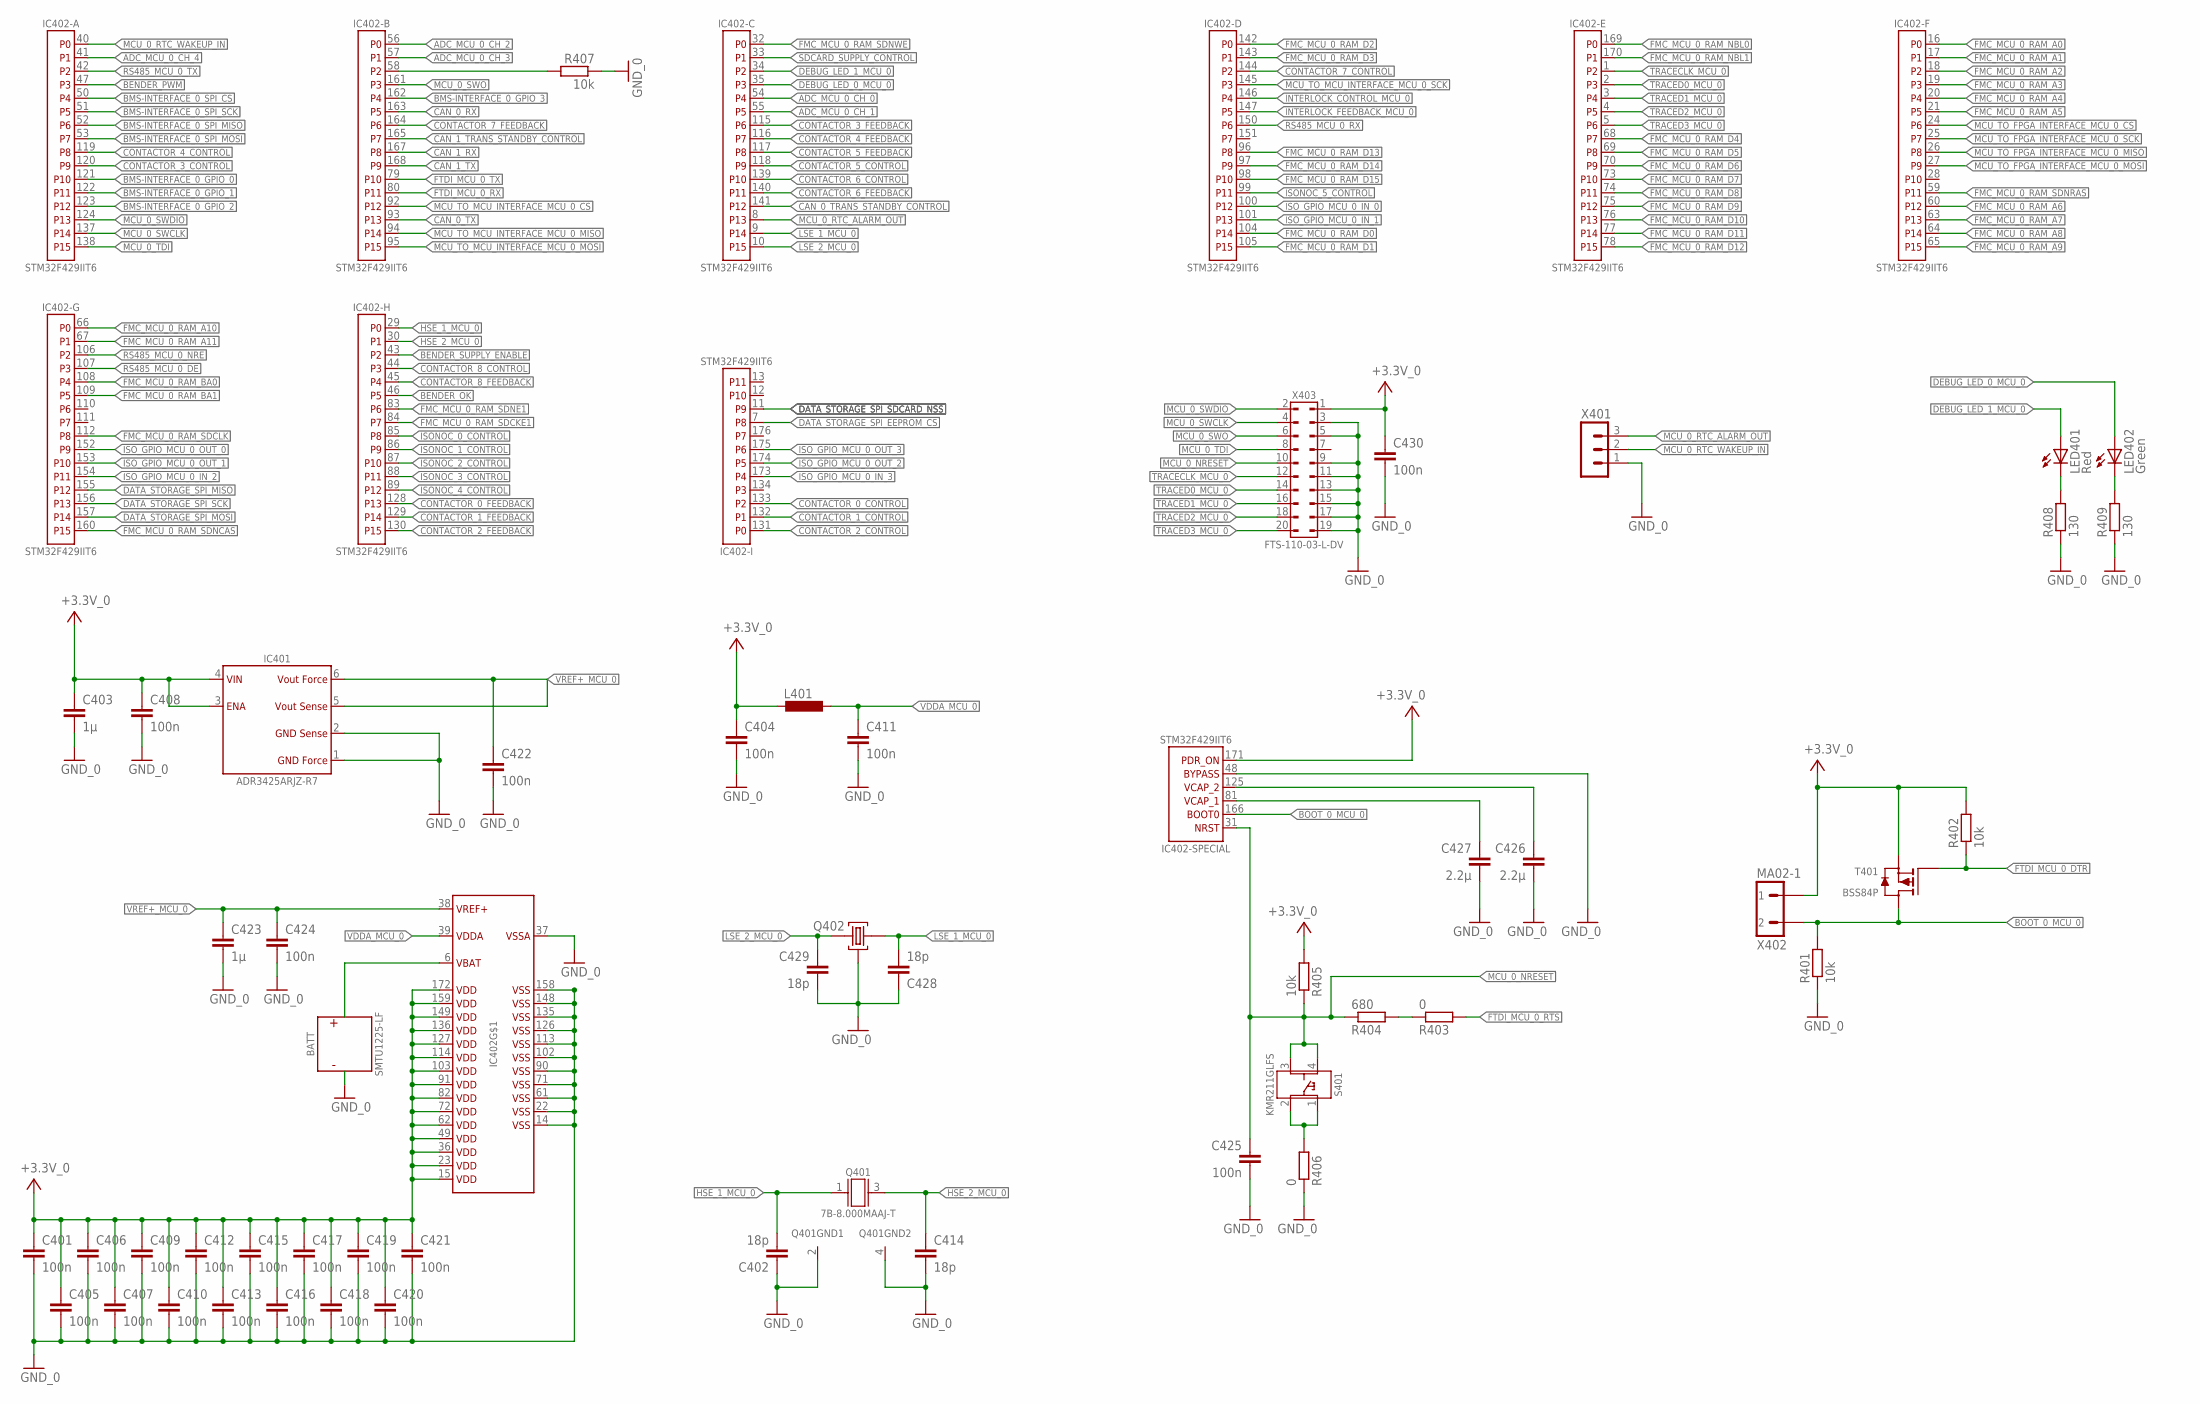
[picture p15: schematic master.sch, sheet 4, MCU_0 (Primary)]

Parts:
BATT: SMTU1225-LF; X_SMD_(23,70MM_X_12,70MM_X_5,00MM)_R_RENATA_REV01
C401, C404, C405, C406, C407, C408, C409, C410, C411, C412, C413, C415, C416, C417, C418, C419, C420, C421, C422, C424, C425, C430: 100n; C0603
C402, C414, C428, C429: 18p; C0603
C403, C423: 1µ; C0603
C426, C427: 2.2µ; C0603
IC401: ADR3425ARJZ; IC_SMD_SOT23-6_(MO-178-AB)_R_AD_REV01
IC402: STM32F429IIT6; IC_SMD_LQFP176_R_ST_REV01
L401: L0805; 0805
LED401: Red; CHIP-LED0603
LED402: Green; CHIP-LED0603
Q401: 7B-8.000MAAJ-T; G_SMD_5,00MM_X_3,20MM_0,90MM_(7B)_TXC_REV01
Q402: MS3V; MS3V-T1R
R401, R402, R405, R407: 10k; R0603
R403, R406: 0; R0603
R404: 680; R0603
R408, R409: 130; R0603
S401: KMR211GLFS; S_SMD_4,60MMX2,80MMX1,90MM_R_CK-COMPONENTS_REV01
T401: BSS84P; V_SMD_SOT23_(TO-236AB)_R_INFINEON_REV01
X401: MA03-1
X402: MA02-1
X403: SAMTEC_FTS_20POL_HEADER_VERTIKAL_REV01; X_SMD_FTS_110-03_(20POL)_R_SAMTEC_REV01

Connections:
+3.3V_0: C401.1, C403.1, C404.1, C405.1, C406.1, C407.1, C408.1, C409.1, C410.1, C412.1, C413.1, C415.1, C416.1, C417.1, C418.1, C419.1, C420.1, C421.1, C430.1, IC401.3 (ENABLE), IC401.4 (VIN), IC402.15 (VDD1), IC402.23 (VDD2), IC402.36 (VDD3), IC402.49 (VDD4), IC402.62 (VDD5), IC402.72 (VDD6), IC402.82 (VDD7), IC402.91 (VDD8), IC402.103 (VDD9), IC402.114 (VDD10), IC402.127 (VDD11), IC402.136 (VDD12), IC402.149 (VDD13), IC402.159 (VDD14), IC402.171 (PDR_ON), IC402.172 (VDD15), L401.1, R402.2, R405.2, T401.2 (S), X402.1, X403.1; also elsewhere on the board
ADC_MCU_0_CH_0: IC402.54 (P4); also elsewhere on the board
ADC_MCU_0_CH_1: IC402.55 (P5); also elsewhere on the board
ADC_MCU_0_CH_2: IC402.56 (P0); also elsewhere on the board
ADC_MCU_0_CH_3: IC402.57 (P1); also elsewhere on the board
ADC_MCU_0_CH_4: IC402.41 (P1); also elsewhere on the board
BENDER_OK: IC402.46 (P5); also elsewhere on the board
BENDER_PWM: IC402.47 (P3); also elsewhere on the board
BENDER_SUPPLY_ENABLE: IC402.43 (P2); also elsewhere on the board
BMS-INTERFACE_0_GPIO_0: IC402.121 (P10); also elsewhere on the board
BMS-INTERFACE_0_GPIO_1: IC402.122 (P11); also elsewhere on the board
BMS-INTERFACE_0_GPIO_2: IC402.123 (P12); also elsewhere on the board
BMS-INTERFACE_0_GPIO_3: IC402.162 (P4); also elsewhere on the board
BMS-INTERFACE_0_SPI_CS: IC402.50 (P4); also elsewhere on the board
BMS-INTERFACE_0_SPI_MISO: IC402.52 (P6); also elsewhere on the board
BMS-INTERFACE_0_SPI_MOSI: IC402.53 (P7); also elsewhere on the board
BMS-INTERFACE_0_SPI_SCK: IC402.51 (P5); also elsewhere on the board
BOOT_0_MCU_0: IC402.166 (BOOT0), R401.2, T401.3 (D), X402.2
CAN_0_RX: IC402.163 (P5); also elsewhere on the board
CAN_0_TRANS_STANDBY_CONTROL: IC402.141 (P12); also elsewhere on the board
CAN_0_TX: IC402.93 (P13); also elsewhere on the board
CAN_1_RX: IC402.167 (P8); also elsewhere on the board
CAN_1_TRANS_STANDBY_CONTROL: IC402.165 (P7); also elsewhere on the board
CAN_1_TX: IC402.168 (P9); also elsewhere on the board
CONTACTOR_0_CONTROL: IC402.133 (P2); also elsewhere on the board
CONTACTOR_0_FEEDBACK: IC402.128 (P13); also elsewhere on the board
CONTACTOR_1_CONTROL: IC402.132 (P1); also elsewhere on the board
CONTACTOR_1_FEEDBACK: IC402.129 (P14); also elsewhere on the board
CONTACTOR_2_CONTROL: IC402.131 (P0); also elsewhere on the board
CONTACTOR_2_FEEDBACK: IC402.130 (P15); also elsewhere on the board
CONTACTOR_3_CONTROL: IC402.120 (P9); also elsewhere on the board
CONTACTOR_3_FEEDBACK: IC402.115 (P6); also elsewhere on the board
CONTACTOR_4_CONTROL: IC402.119 (P8); also elsewhere on the board
CONTACTOR_4_FEEDBACK: IC402.116 (P7); also elsewhere on the board
CONTACTOR_5_CONTROL: IC402.118 (P9); also elsewhere on the board
CONTACTOR_5_FEEDBACK: IC402.117 (P8); also elsewhere on the board
CONTACTOR_6_CONTROL: IC402.139 (P10); also elsewhere on the board
CONTACTOR_6_FEEDBACK: IC402.140 (P11); also elsewhere on the board
CONTACTOR_7_CONTROL: IC402.144 (P2); also elsewhere on the board
CONTACTOR_7_FEEDBACK: IC402.164 (P6); also elsewhere on the board
CONTACTOR_8_CONTROL: IC402.44 (P3); also elsewhere on the board
CONTACTOR_8_FEEDBACK: IC402.45 (P4); also elsewhere on the board
DATA_STORAGE_SPI_EEPROM_CS: IC402.7 (P8); also elsewhere on the board
DATA_STORAGE_SPI_MISO: IC402.155 (P12); also elsewhere on the board
DATA_STORAGE_SPI_MOSI: IC402.157 (P14); also elsewhere on the board
DATA_STORAGE_SPI_SCK: IC402.156 (P13); also elsewhere on the board
DATA_STORAGE_SPI_SDCARD_NSS: IC402.11 (P9); also elsewhere on the board
DEBUG_LED_0_MCU_0: IC402.35 (P3), LED402.A
DEBUG_LED_1_MCU_0: IC402.34 (P2), LED401.A
FMC_MCU_0_RAM_A0: IC402.16 (P0); also elsewhere on the board
FMC_MCU_0_RAM_A1: IC402.17 (P1); also elsewhere on the board
FMC_MCU_0_RAM_A2: IC402.18 (P2); also elsewhere on the board
FMC_MCU_0_RAM_A3: IC402.19 (P3); also elsewhere on the board
FMC_MCU_0_RAM_A4: IC402.20 (P4); also elsewhere on the board
FMC_MCU_0_RAM_A5: IC402.21 (P5); also elsewhere on the board
FMC_MCU_0_RAM_A6: IC402.60 (P12); also elsewhere on the board
FMC_MCU_0_RAM_A7: IC402.63 (P13); also elsewhere on the board
FMC_MCU_0_RAM_A8: IC402.64 (P14); also elsewhere on the board
FMC_MCU_0_RAM_A9: IC402.65 (P15); also elsewhere on the board
FMC_MCU_0_RAM_A10: IC402.66 (P0); also elsewhere on the board
FMC_MCU_0_RAM_A11: IC402.67 (P1); also elsewhere on the board
FMC_MCU_0_RAM_BA0: IC402.108 (P4); also elsewhere on the board
FMC_MCU_0_RAM_BA1: IC402.109 (P5); also elsewhere on the board
FMC_MCU_0_RAM_D0: IC402.104 (P14); also elsewhere on the board
FMC_MCU_0_RAM_D1: IC402.105 (P15); also elsewhere on the board
FMC_MCU_0_RAM_D2: IC402.142 (P0); also elsewhere on the board
FMC_MCU_0_RAM_D3: IC402.143 (P1); also elsewhere on the board
FMC_MCU_0_RAM_D4: IC402.68 (P7); also elsewhere on the board
FMC_MCU_0_RAM_D5: IC402.69 (P8); also elsewhere on the board
FMC_MCU_0_RAM_D6: IC402.70 (P9); also elsewhere on the board
FMC_MCU_0_RAM_D7: IC402.73 (P10); also elsewhere on the board
FMC_MCU_0_RAM_D8: IC402.74 (P11); also elsewhere on the board
FMC_MCU_0_RAM_D9: IC402.75 (P12); also elsewhere on the board
FMC_MCU_0_RAM_D10: IC402.76 (P13); also elsewhere on the board
FMC_MCU_0_RAM_D11: IC402.77 (P14); also elsewhere on the board
FMC_MCU_0_RAM_D12: IC402.78 (P15); also elsewhere on the board
FMC_MCU_0_RAM_D13: IC402.96 (P8); also elsewhere on the board
FMC_MCU_0_RAM_D14: IC402.97 (P9); also elsewhere on the board
FMC_MCU_0_RAM_D15: IC402.98 (P10); also elsewhere on the board
FMC_MCU_0_RAM_NBL0: IC402.169 (P0); also elsewhere on the board
FMC_MCU_0_RAM_NBL1: IC402.170 (P1); also elsewhere on the board
FMC_MCU_0_RAM_SDCKE1: IC402.84 (P7); also elsewhere on the board
FMC_MCU_0_RAM_SDCLK: IC402.112 (P8); also elsewhere on the board
FMC_MCU_0_RAM_SDNCAS: IC402.160 (P15); also elsewhere on the board
FMC_MCU_0_RAM_SDNE1: IC402.83 (P6); also elsewhere on the board
FMC_MCU_0_RAM_SDNRAS: IC402.59 (P11); also elsewhere on the board
FMC_MCU_0_RAM_SDNWE: IC402.32 (P0); also elsewhere on the board
FTDI_MCU_0_DTR: R402.1, T401.1 (G); also elsewhere on the board
FTDI_MCU_0_RTS: R403.2; also elsewhere on the board
FTDI_MCU_0_RX: IC402.80 (P11); also elsewhere on the board
FTDI_MCU_0_TX: IC402.79 (P10); also elsewhere on the board
GND_0: BATT.-, C401.2, C402.1, C403.2, C404.2, C405.2, C406.2, C407.2, C408.2, C409.2, C410.2, C411.2, C412.2, C413.2, C414.2, C415.2, C416.2, C417.2, C418.2, C419.2, C420.2, C421.2, C422.2, C423.2, C424.2, C425.2, C426.2, C427.2, C428.1, C429.2, C430.2, IC401.1 (GND_FORCE), IC401.2 (GND_SENSE), IC402.14 (VSS1), IC402.22 (VSS2), IC402.37 (VSSA), IC402.48 (BYPASS_REG), IC402.61 (VSS3), IC402.71 (VSS4), IC402.90 (VSS5), IC402.102 (VSS6), IC402.113 (VSS7), IC402.126 (VSS8), IC402.135 (VSS9), IC402.148 (VSS10), IC402.158 (VSS11), Q401.2 (GND), Q401.4 (GND), Q402.P$3 (2), R401.1, R406.1, R407.1, R408.1, R409.1, X401.1, X403.3, X403.5, X403.9, X403.11, X403.13, X403.15, X403.17, X403.19; also elsewhere on the board
HSE_1_MCU_0: C402.2, IC402.29 (P0), Q401.1 (A)
HSE_2_MCU_0: C414.1, IC402.30 (P1), Q401.3 (B)
INTERLOCK_CONTROL_MCU_0: IC402.146 (P4); also elsewhere on the board
INTERLOCK_FEEDBACK_MCU_0: IC402.147 (P5); also elsewhere on the board
ISONOC_0_CONTROL: IC402.85 (P8); also elsewhere on the board
ISONOC_1_CONTROL: IC402.86 (P9); also elsewhere on the board
ISONOC_2_CONTROL: IC402.87 (P10); also elsewhere on the board
ISONOC_3_CONTROL: IC402.88 (P11); also elsewhere on the board
ISONOC_4_CONTROL: IC402.89 (P12); also elsewhere on the board
ISONOC_5_CONTROL: IC402.99 (P11); also elsewhere on the board
ISO_GPIO_MCU_0_IN_0: IC402.100 (P12); also elsewhere on the board
ISO_GPIO_MCU_0_IN_1: IC402.101 (P13); also elsewhere on the board
ISO_GPIO_MCU_0_IN_2: IC402.154 (P11); also elsewhere on the board
ISO_GPIO_MCU_0_IN_3: IC402.173 (P4); also elsewhere on the board
ISO_GPIO_MCU_0_OUT_0: IC402.152 (P9); also elsewhere on the board
ISO_GPIO_MCU_0_OUT_1: IC402.153 (P10); also elsewhere on the board
ISO_GPIO_MCU_0_OUT_2: IC402.174 (P5); also elsewhere on the board
ISO_GPIO_MCU_0_OUT_3: IC402.175 (P6); also elsewhere on the board
LSE_1_MCU_0: C428.2, IC402.9 (P14), Q402.1
LSE_2_MCU_0: C429.1, IC402.10 (P15), Q402.2 (3)
MCU_0_NRESET: C425.1, IC402.31 (NRST), R404.1, R405.1, S401.3, S401.4, X403.10
MCU_0_RTC_ALARM_OUT: IC402.8 (P13), X401.3
MCU_0_RTC_WAKEUP_IN: IC402.40 (P0), X401.2
MCU_0_SWCLK: IC402.137 (P14), X403.4
MCU_0_SWDIO: IC402.124 (P13), X403.2
MCU_0_SWO: IC402.161 (P3), X403.6
MCU_0_TDI: IC402.138 (P15), X403.8
MCU_TO_FPGA_INTERFACE_MCU_0_CS: IC402.24 (P6); also elsewhere on the board
MCU_TO_FPGA_INTERFACE_MCU_0_MISO: IC402.26 (P8); also elsewhere on the board
MCU_TO_FPGA_INTERFACE_MCU_0_MOSI: IC402.27 (P9); also elsewhere on the board
MCU_TO_FPGA_INTERFACE_MCU_0_SCK: IC402.25 (P7); also elsewhere on the board
MCU_TO_MCU_INTERFACE_MCU_0_CS: IC402.92 (P12); also elsewhere on the board
MCU_TO_MCU_INTERFACE_MCU_0_MISO: IC402.94 (P14); also elsewhere on the board
MCU_TO_MCU_INTERFACE_MCU_0_MOSI: IC402.95 (P15); also elsewhere on the board
MCU_TO_MCU_INTERFACE_MCU_0_SCK: IC402.145 (P3); also elsewhere on the board
unnamed: C426.1, IC402.125 (VCAP_2)
unnamed: R406.2, S401.1, S401.2
unnamed: LED401.C, R408.2
unnamed: LED402.C, R409.2
unnamed: C427.1, IC402.81 (VCAP_1)
unnamed: IC402.58 (P2), R407.2
unnamed: R403.1, R404.2
unnamed: BATT.+, IC402.6 (VBAT)
RS485_MCU_0_DE: IC402.107 (P3); also elsewhere on the board
RS485_MCU_0_NRE: IC402.106 (P2); also elsewhere on the board
RS485_MCU_0_RX: IC402.150 (P6); also elsewhere on the board
RS485_MCU_0_TX: IC402.42 (P2); also elsewhere on the board
SDCARD_SUPPLY_CONTROL: IC402.33 (P1); also elsewhere on the board
TRACECLK_MCU_0: IC402.1 (P2), X403.12
TRACED0_MCU_0: IC402.2 (P3), X403.14
TRACED1_MCU_0: IC402.3 (P4), X403.16
TRACED2_MCU_0: IC402.4 (P5), X403.18
TRACED3_MCU_0: IC402.5 (P6), X403.20
VDDA_MCU_0: C411.1, IC402.39 (VDDA), L401.2
VREF+_MCU_0: C422.1, C423.1, C424.1, IC401.5 (VOUT_SENSE), IC401.6 (VOUT_FORCE), IC402.38 (VREF+)

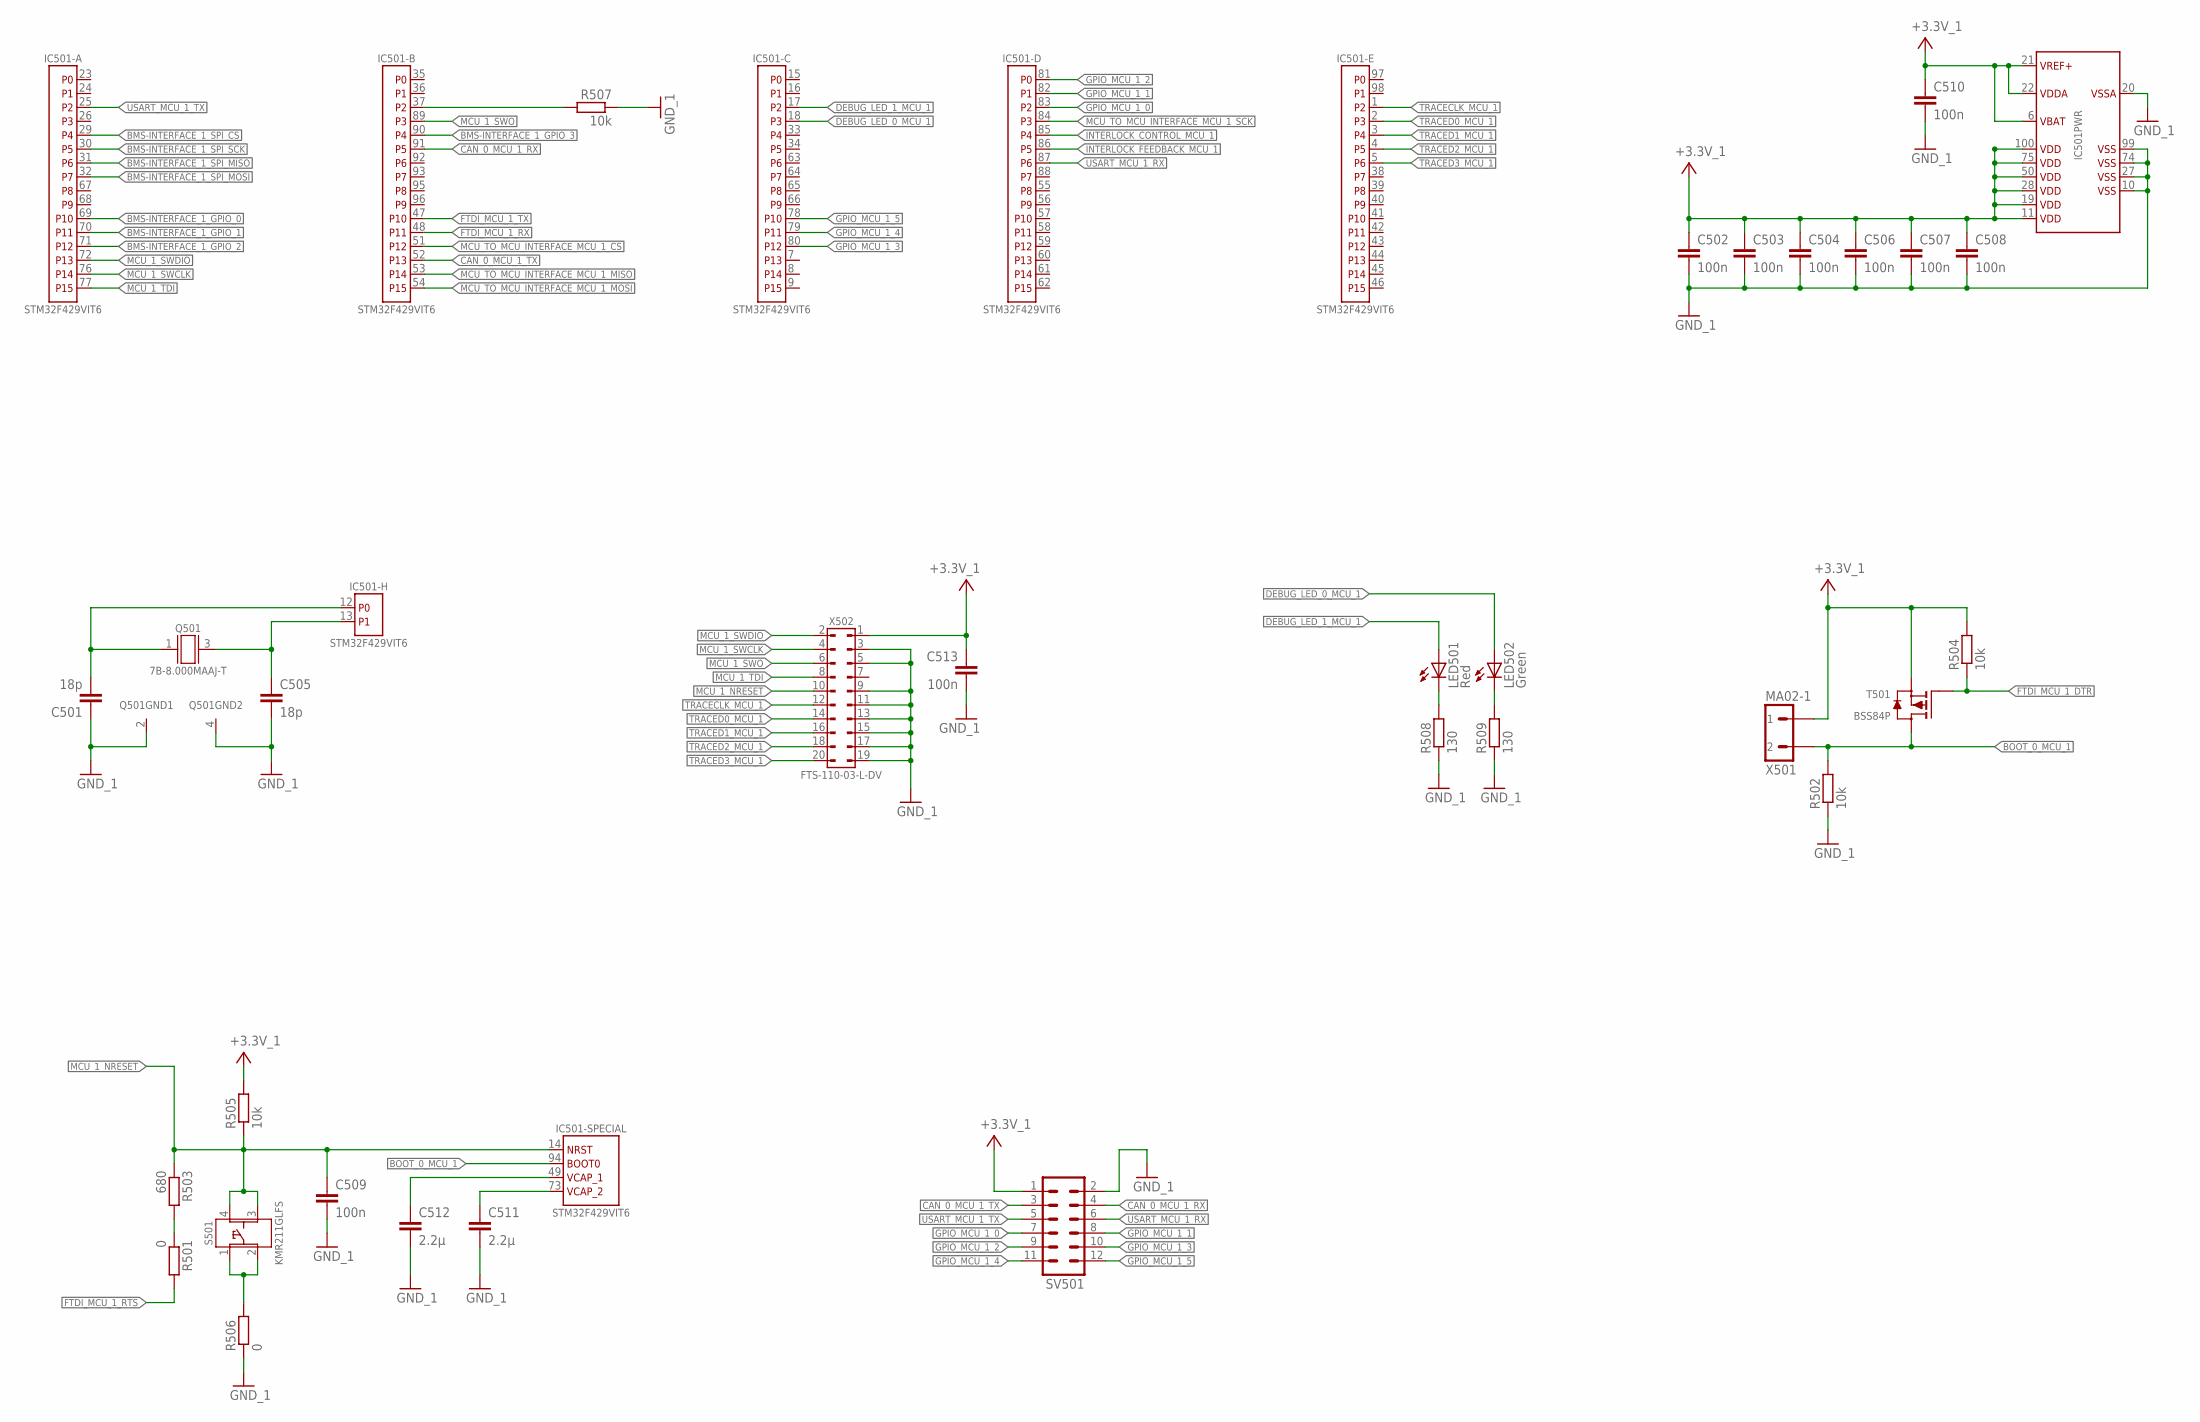
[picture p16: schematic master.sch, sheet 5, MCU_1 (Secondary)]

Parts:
C501, C505: 18p; C0603
C502, C503, C504, C506, C507, C508, C509, C510, C513: 100n; C0603
C511, C512: 2.2µ; C0603
IC501: STM32F429VIT6; IC_SMD_LQFP100_R_ST_REV01
LED501: Red; CHIP-LED0603
LED502: Green; CHIP-LED0603
Q501: 7B-8.000MAAJ-T; G_SMD_5,00MM_X_3,20MM_0,90MM_(7B)_TXC_REV01
R501, R506: 0; R0603
R502, R504, R505, R507: 10k; R0603
R503: 680; R0603
R508, R509: 130; R0603
S501: KMR211GLFS; S_SMD_4,60MMX2,80MMX1,90MM_R_CK-COMPONENTS_REV01
SV501: MA06-2
T501: BSS84P; V_SMD_SOT23_(TO-236AB)_R_INFINEON_REV01
X501: MA02-1
X502: SAMTEC_FTS_20POL_HEADER_VERTIKAL_REV01; X_SMD_FTS_110-03_(20POL)_R_SAMTEC_REV01

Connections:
+3.3V_1: C502.1, C503.1, C504.1, C506.1, C507.1, C508.1, C510.1, C513.1, IC501.6 (VBAT), IC501.11 (VDD1), IC501.19 (VDD2), IC501.21 (VREF+), IC501.22 (VDDA), IC501.28 (VDD3), IC501.50 (VDD4), IC501.75 (VDD5), IC501.100 (VDD6), R504.2, R505.2, SV501.1, T501.2 (S), X501.1, X502.1; also elsewhere on the board
BMS-INTERFACE_1_GPIO_0: IC501.69 (P10); also elsewhere on the board
BMS-INTERFACE_1_GPIO_1: IC501.70 (P11); also elsewhere on the board
BMS-INTERFACE_1_GPIO_2: IC501.71 (P12); also elsewhere on the board
BMS-INTERFACE_1_GPIO_3: IC501.90 (P4); also elsewhere on the board
BMS-INTERFACE_1_SPI_CS: IC501.29 (P4); also elsewhere on the board
BMS-INTERFACE_1_SPI_MISO: IC501.31 (P6); also elsewhere on the board
BMS-INTERFACE_1_SPI_MOSI: IC501.32 (P7); also elsewhere on the board
BMS-INTERFACE_1_SPI_SCK: IC501.30 (P5); also elsewhere on the board
BOOT_0_MCU_1: IC501.94 (BOOT0), R502.2, T501.3 (D), X501.2
CAN_0_MCU_1_RX: IC501.91 (P5), SV501.4
CAN_0_MCU_1_TX: IC501.52 (P13), SV501.3
DEBUG_LED_0_MCU_1: IC501.18 (P3), LED502.A
DEBUG_LED_1_MCU_1: IC501.17 (P2), LED501.A
FTDI_MCU_1_DTR: R504.1, T501.1 (G); also elsewhere on the board
FTDI_MCU_1_RTS: R501.2; also elsewhere on the board
FTDI_MCU_1_RX: IC501.48 (P11); also elsewhere on the board
FTDI_MCU_1_TX: IC501.47 (P10); also elsewhere on the board
GND_1: C501.1, C502.2, C503.2, C504.2, C505.2, C506.2, C507.2, C508.2, C509.2, C510.2, C511.2, C512.2, C513.2, IC501.10 (VSS1), IC501.20 (VSSA), IC501.27 (VSS2), IC501.74 (VSS3), IC501.99 (VSS4), Q501.2 (GND), Q501.4 (GND), R502.1, R506.1, R507.1, R508.1, R509.1, SV501.2, X502.3, X502.5, X502.9, X502.11, X502.13, X502.15, X502.17, X502.19; also elsewhere on the board
GPIO_MCU_1_0: IC501.83 (P2), SV501.7
GPIO_MCU_1_1: IC501.82 (P1), SV501.8
GPIO_MCU_1_2: IC501.81 (P0), SV501.9
GPIO_MCU_1_3: IC501.80 (P12), SV501.10
GPIO_MCU_1_4: IC501.79 (P11), SV501.11
GPIO_MCU_1_5: IC501.78 (P10), SV501.12
INTERLOCK_CONTROL_MCU_1: IC501.85 (P4); also elsewhere on the board
INTERLOCK_FEEDBACK_MCU_1: IC501.86 (P5); also elsewhere on the board
MCU_1_NRESET: C509.1, IC501.14 (NRST), R503.1, R505.1, S501.3, S501.4, X502.10
MCU_1_SWCLK: IC501.76 (P14), X502.4
MCU_1_SWDIO: IC501.72 (P13), X502.2
MCU_1_SWO: IC501.89 (P3), X502.6
MCU_1_TDI: IC501.77 (P15), X502.8
MCU_TO_MCU_INTERFACE_MCU_1_CS: IC501.51 (P12); also elsewhere on the board
MCU_TO_MCU_INTERFACE_MCU_1_MISO: IC501.53 (P14); also elsewhere on the board
MCU_TO_MCU_INTERFACE_MCU_1_MOSI: IC501.54 (P15); also elsewhere on the board
MCU_TO_MCU_INTERFACE_MCU_1_SCK: IC501.84 (P3); also elsewhere on the board
unnamed: C501.2, IC501.12 (P0), Q501.1 (A)
unnamed: C505.1, IC501.13 (P1), Q501.3 (B)
unnamed: R506.2, S501.1, S501.2
unnamed: LED502.C, R509.2
unnamed: LED501.C, R508.2
unnamed: C511.1, IC501.73 (VCAP_2)
unnamed: C512.1, IC501.49 (VCAP_1)
unnamed: IC501.37 (P2), R507.2
unnamed: R501.1, R503.2
TRACECLK_MCU_1: IC501.1 (P2), X502.12
TRACED0_MCU_1: IC501.2 (P3), X502.14
TRACED1_MCU_1: IC501.3 (P4), X502.16
TRACED2_MCU_1: IC501.4 (P5), X502.18
TRACED3_MCU_1: IC501.5 (P6), X502.20
USART_MCU_1_RX: IC501.87 (P6), SV501.6
USART_MCU_1_TX: IC501.25 (P2), SV501.5

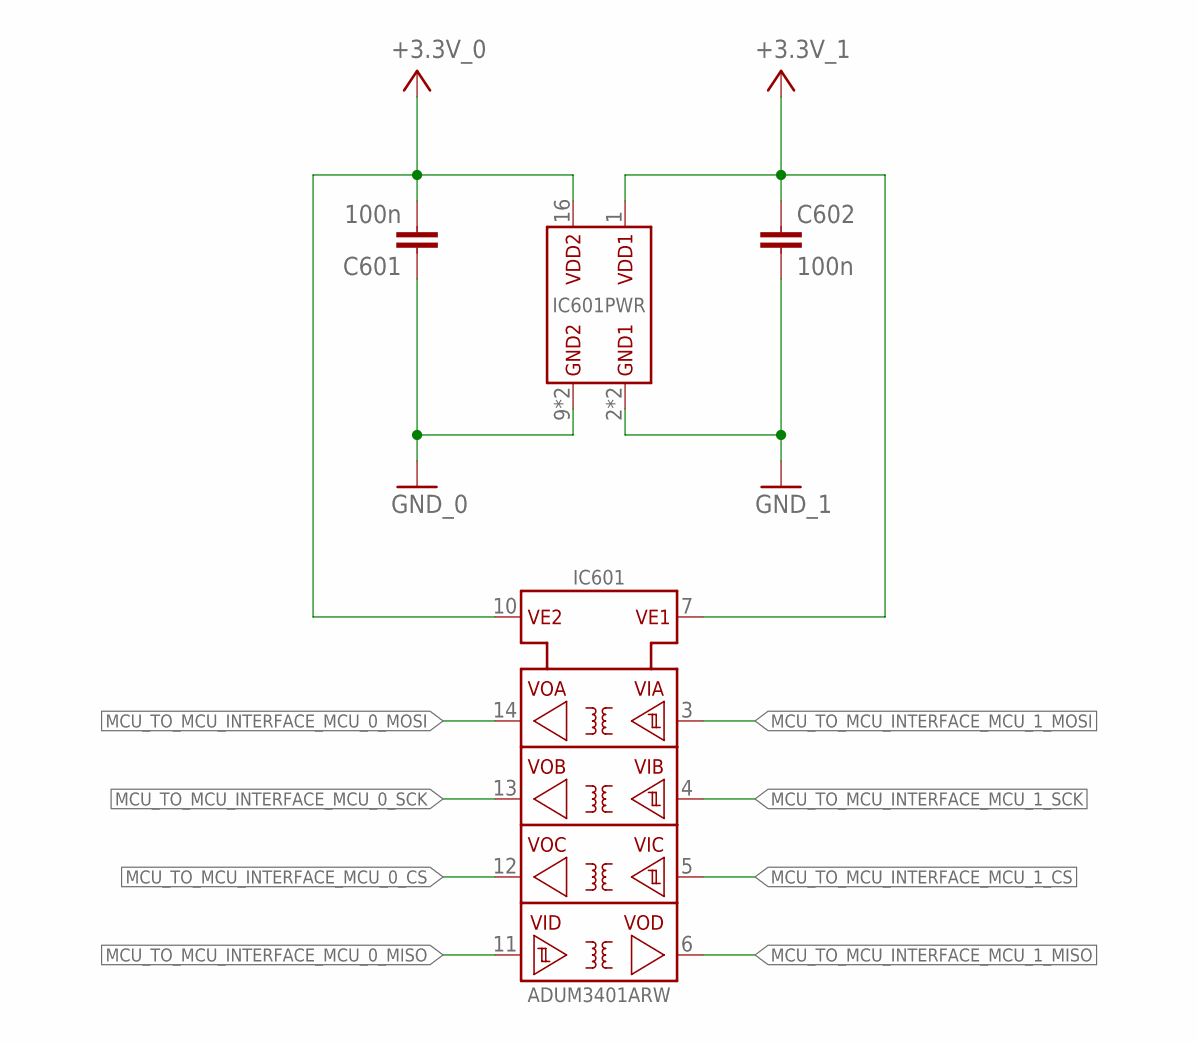
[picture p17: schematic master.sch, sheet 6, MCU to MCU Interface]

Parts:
C601, C602: 100n; C0603
IC601: ADUM3401ARW; IC_SMD_SOIC-16_(JEDEC_MS-013-AA)_R_ANALOG_REV01

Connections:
+3.3V_0: C601.2, IC601.10 (VE2), IC601.16 (VDD2); also elsewhere on the board
+3.3V_1: C602.1, IC601.1 (VDD1), IC601.7 (VE1); also elsewhere on the board
GND_0: C601.1, IC601.9 (GND2), IC601.15 (GND2); also elsewhere on the board
GND_1: C602.2, IC601.2 (GND1), IC601.8 (GND1); also elsewhere on the board
MCU_TO_MCU_INTERFACE_MCU_0_CS: IC601.12 (VOC); also elsewhere on the board
MCU_TO_MCU_INTERFACE_MCU_0_MISO: IC601.11 (VID); also elsewhere on the board
MCU_TO_MCU_INTERFACE_MCU_0_MOSI: IC601.14 (VOA); also elsewhere on the board
MCU_TO_MCU_INTERFACE_MCU_0_SCK: IC601.13 (VOB); also elsewhere on the board
MCU_TO_MCU_INTERFACE_MCU_1_CS: IC601.5 (VIC); also elsewhere on the board
MCU_TO_MCU_INTERFACE_MCU_1_MISO: IC601.6 (VOD); also elsewhere on the board
MCU_TO_MCU_INTERFACE_MCU_1_MOSI: IC601.3 (VIA); also elsewhere on the board
MCU_TO_MCU_INTERFACE_MCU_1_SCK: IC601.4 (VIB); also elsewhere on the board

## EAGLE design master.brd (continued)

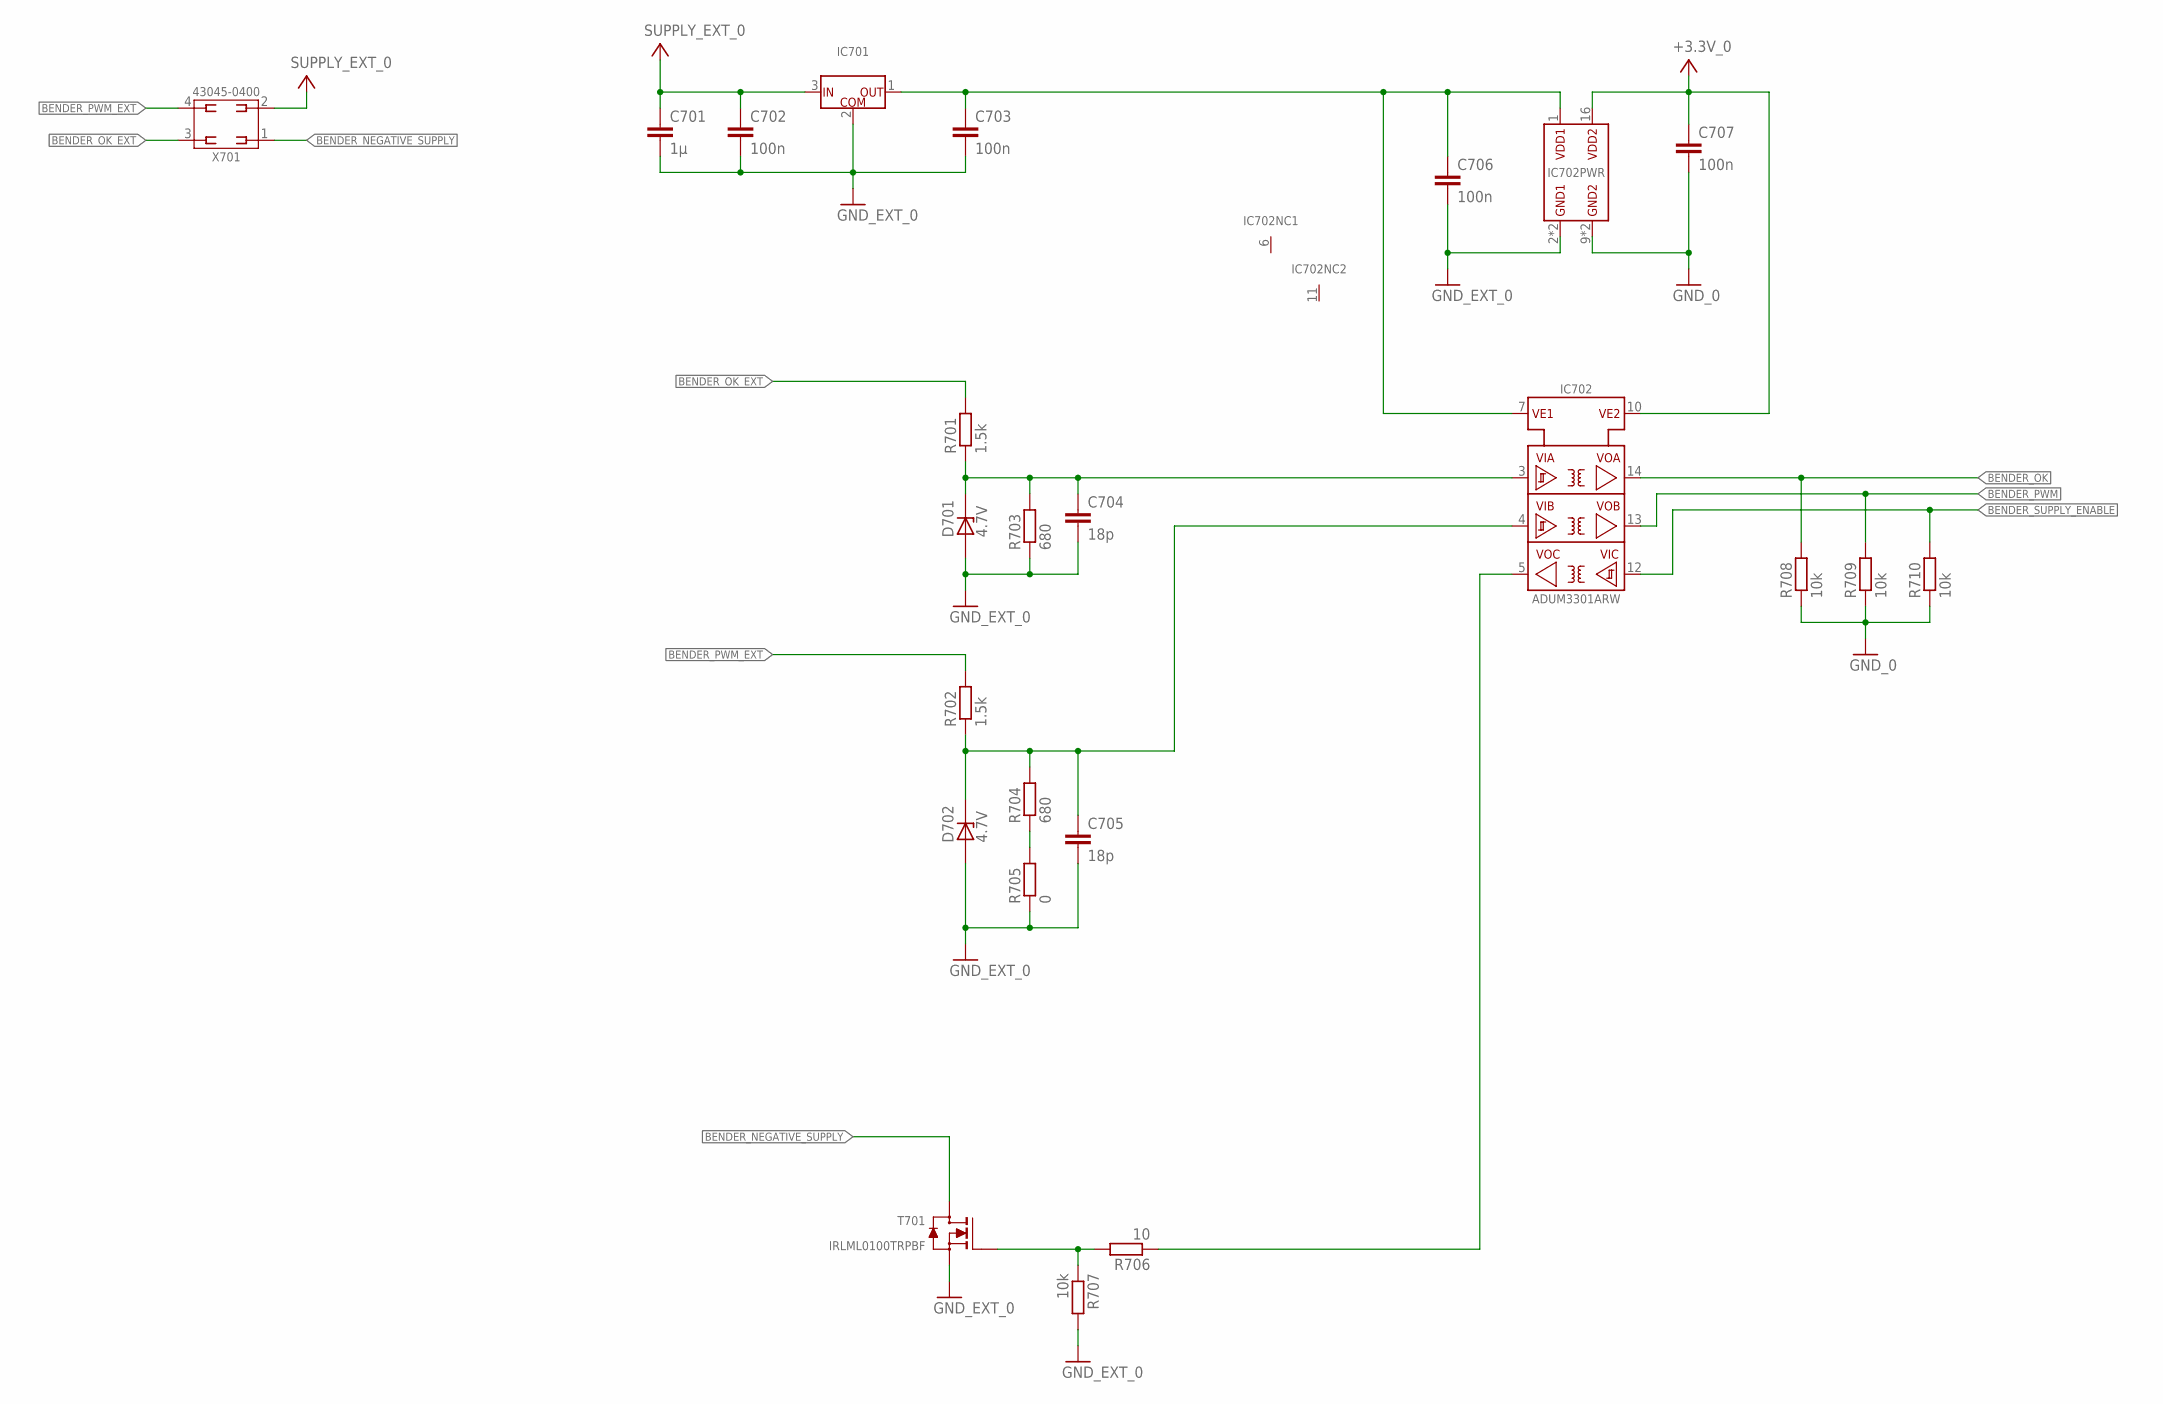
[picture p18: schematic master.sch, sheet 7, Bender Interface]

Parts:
C701: 1µ; C0603
C702, C703, C706, C707: 100n; C0603
C704, C705: 18p; C0603
D701, D702: 4.7V; SOD323
IC701: UA78L05ACPK; IC_SMD_SOT-89_(SC-62/TO-243)_(R-PSSO-F3)_R_TI_REV01
IC702: ADUM3301ARW; IC_SMD_SOIC-16_(JEDEC_MS-013-AA)_R_ANALOG_REV01
R701, R702: 1.5k; R0603
R703, R704: 680; R0603
R705: 0; R0603
R706: 10; R0603
R707, R708, R709, R710: 10k; R0603
T701: IRLML0100TRPBF; V_SMD_SOT-23_(TO-236AB)_R_IR_REV01
X701: 43045-0400_MOLEX_4PIN; X_TH_MOLEX_43045-0400_R_REV01

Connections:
+3.3V_0: C707.1, IC702.10 (VE2), IC702.16 (VDD2); also elsewhere on the board
BENDER_ADUM_SUPPLY: C703.1, C706.1, IC701.1 (OUT), IC702.1 (VDD1), IC702.7 (VE1)
BENDER_NEGATIVE_SUPPLY: T701.3 (D), X701.1
BENDER_OK: IC702.14 (VOA), R708.2; also elsewhere on the board
BENDER_OK_EXT: R701.2, X701.3
BENDER_PWM: IC702.13 (VOB), R709.2; also elsewhere on the board
BENDER_PWM_EXT: R702.2, X701.4
BENDER_SUPPLY_ENABLE: IC702.12 (VIC), R710.2; also elsewhere on the board
GND_0: C707.2, IC702.9 (GND2), IC702.15 (GND2), R708.1, R709.1, R710.1; also elsewhere on the board
GND_EXT_0: C701.2, C702.2, C703.2, C704.2, C705.2, C706.2, D701.A, D702.A, IC701.2 (COM), IC702.2 (GND1), IC702.8 (GND1), R703.1, R705.1, R707.2, T701.2 (S); also elsewhere on the board
unnamed: IC702.5 (VOC), R706.1
unnamed: R706.2, R707.1, T701.1 (G)
unnamed: C705.1, D702.C (K), IC702.4 (VIB), R702.1, R704.2
unnamed: C704.1, D701.C (K), IC702.3 (VIA), R701.1, R703.2
unnamed: R704.1, R705.2
SUPPLY_EXT_0: C701.1, C702.1, IC701.3 (IN), X701.2; also elsewhere on the board

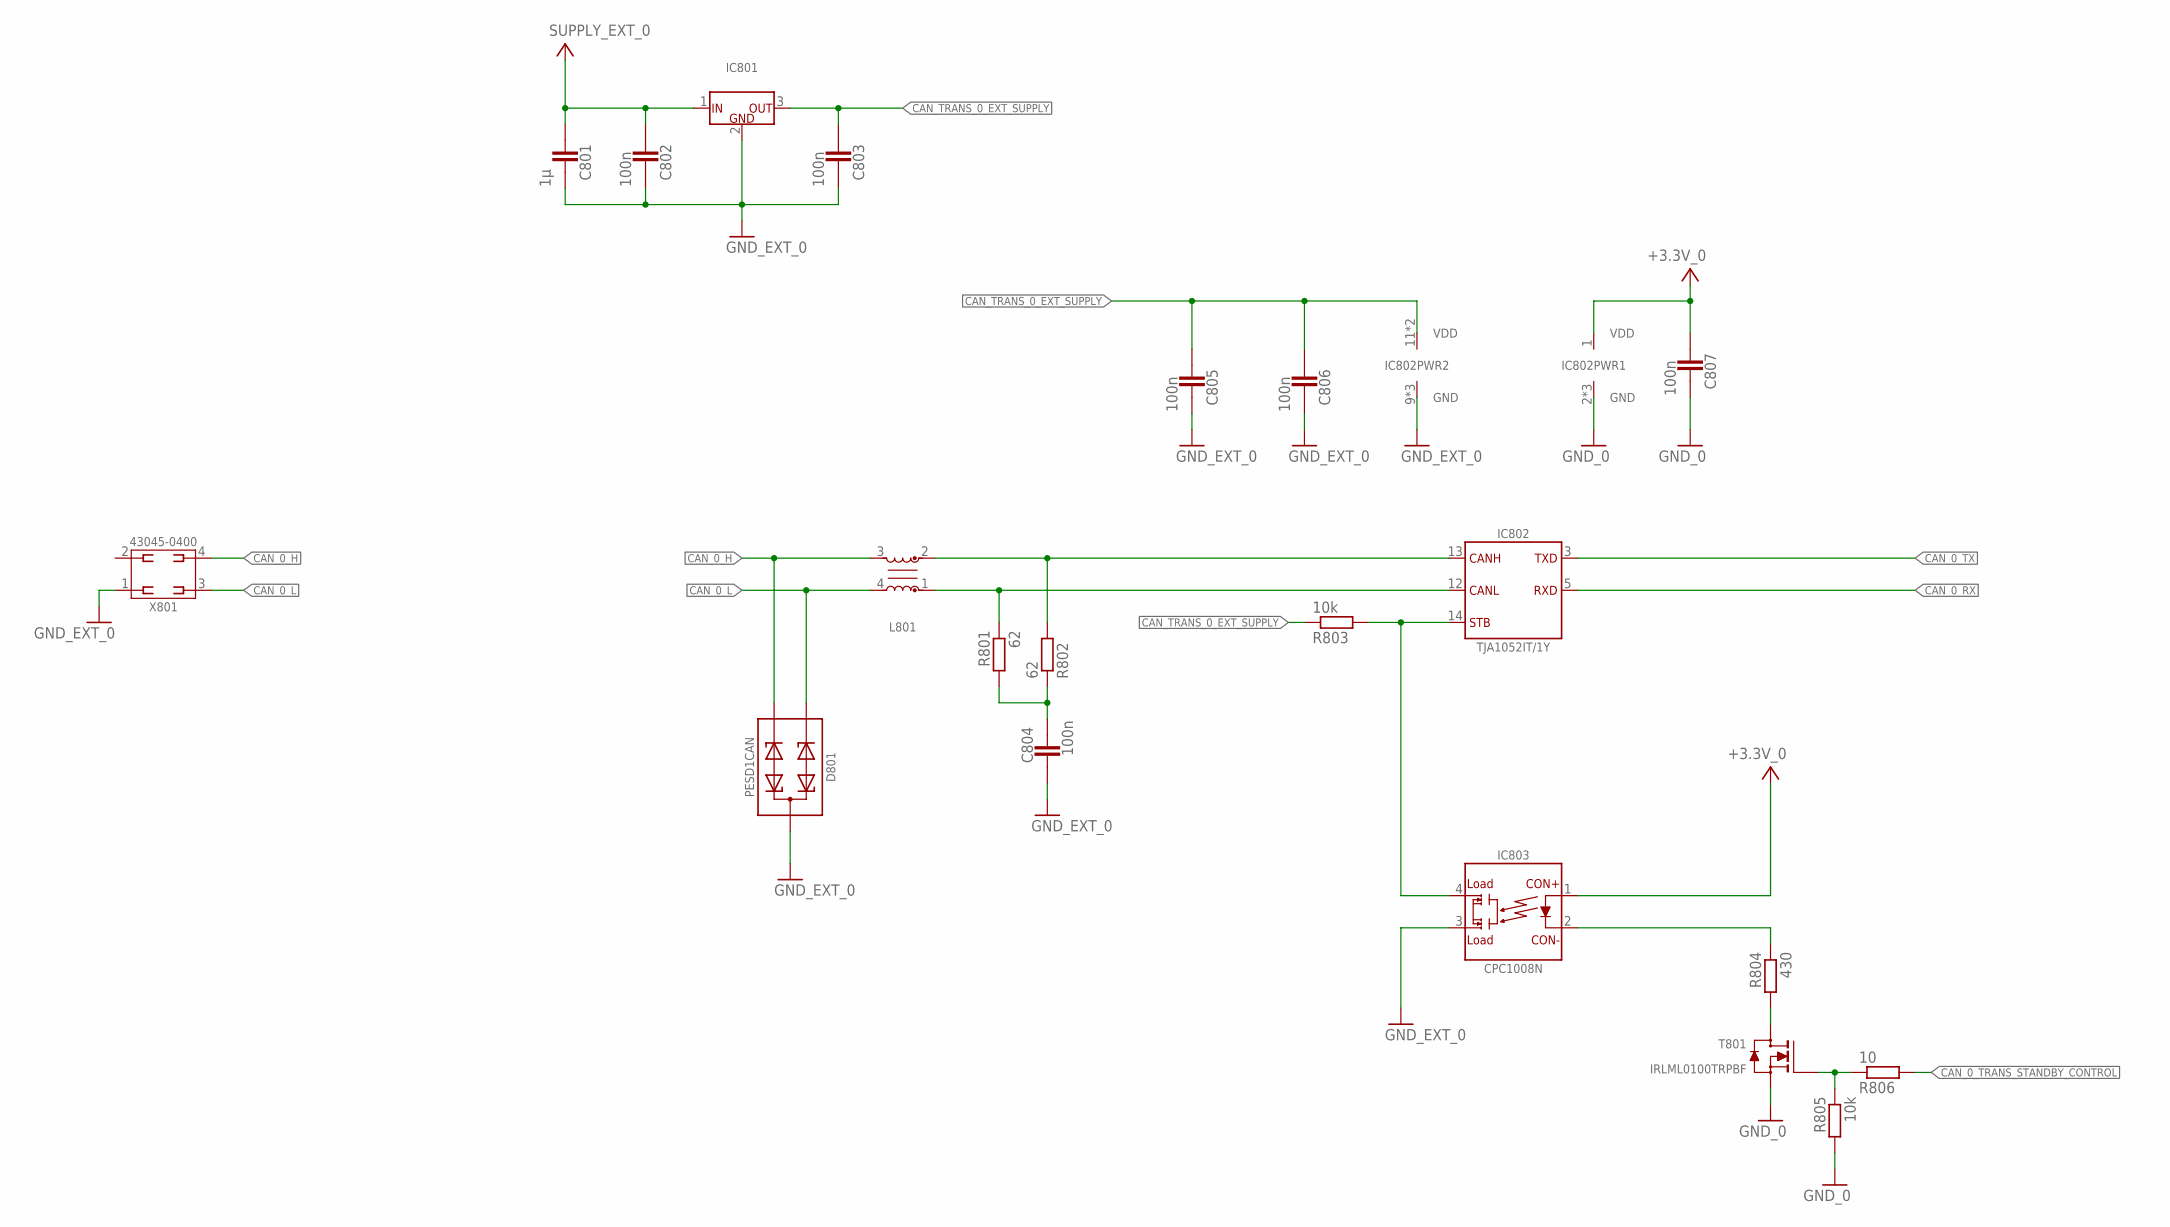
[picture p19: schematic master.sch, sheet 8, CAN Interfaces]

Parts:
C801: 1µ; 0603
C802, C803, C804, C805, C806, C807: 100n; 0603
D801: PESD1CAN; D_SMD_SOT23_(TO-236AB)_R_NXP_REV01
IC801: KA7805ERTF; IC_SMD_TO-252_(D-PAK)_R_FAIRCHILD_REV01
IC802: TJA1052IT/1Y; IC_SMD_SO16_(SOT162-1)_R_NXP_REV01
IC803: CPC1008N; K_SMD_SOP-4_R_IXYS_REV01
L801: B82789C0513H001; L_SMD_FILTER_HF_R_EPCOS_SIMDAD_1812_REV01
R801, R802: 62; R0603
R803, R805: 10k; 0603
R804: 430; 0603
R806: 10; 0603
T801: IRLML0100TRPBF; V_SMD_SOT-23_(TO-236AB)_R_IR_REV01
X801: 43045-0400_MOLEX_4PIN; X_TH_MOLEX_43045-0400_R_REV01

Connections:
+3.3V_0: C807.2, IC802.1 (VDD), IC803.1 (CON+); also elsewhere on the board
CAN_0_H: D801.2, L801.3, X801.4
CAN_0_L: D801.1, L801.4, X801.3
CAN_0_RX: IC802.5 (RXD); also elsewhere on the board
CAN_0_TRANS_STANDBY_CONTROL: R806.2; also elsewhere on the board
CAN_0_TX: IC802.3 (TXD); also elsewhere on the board
CAN_L_INT: IC802.12 (CANL), L801.1, R801.1
CAN_SPLIT: C804.1, R801.2, R802.1
CAN_TRANS_0_EXT_SUPPLY: C803.2, C805.2, C806.2, IC801.3 (OUT), IC802.11 (VDD), IC802.16 (VDD), R803.1
CAN_TRANS_0_STANDBY: IC802.14 (STB), IC803.4, R803.2
GND_0: C807.1, IC802.2 (GND), IC802.7 (GND), IC802.8 (GND), R805.2, T801.2 (S); also elsewhere on the board
GND_EXT_0: C801.1, C802.1, C803.1, C804.2, C805.1, C806.1, D801.3, IC801.2 (GND), IC802.9 (GND), IC802.10 (GND), IC802.15 (GND), IC803.3, X801.1; also elsewhere on the board
unnamed: R804.2, T801.3 (D)
unnamed: IC802.13 (CANH), L801.2, R802.2
unnamed: IC803.2 (CON-), R804.1
unnamed: R805.1, R806.1, T801.1 (G)
SUPPLY_EXT_0: C801.2, C802.2, IC801.1 (IN); also elsewhere on the board

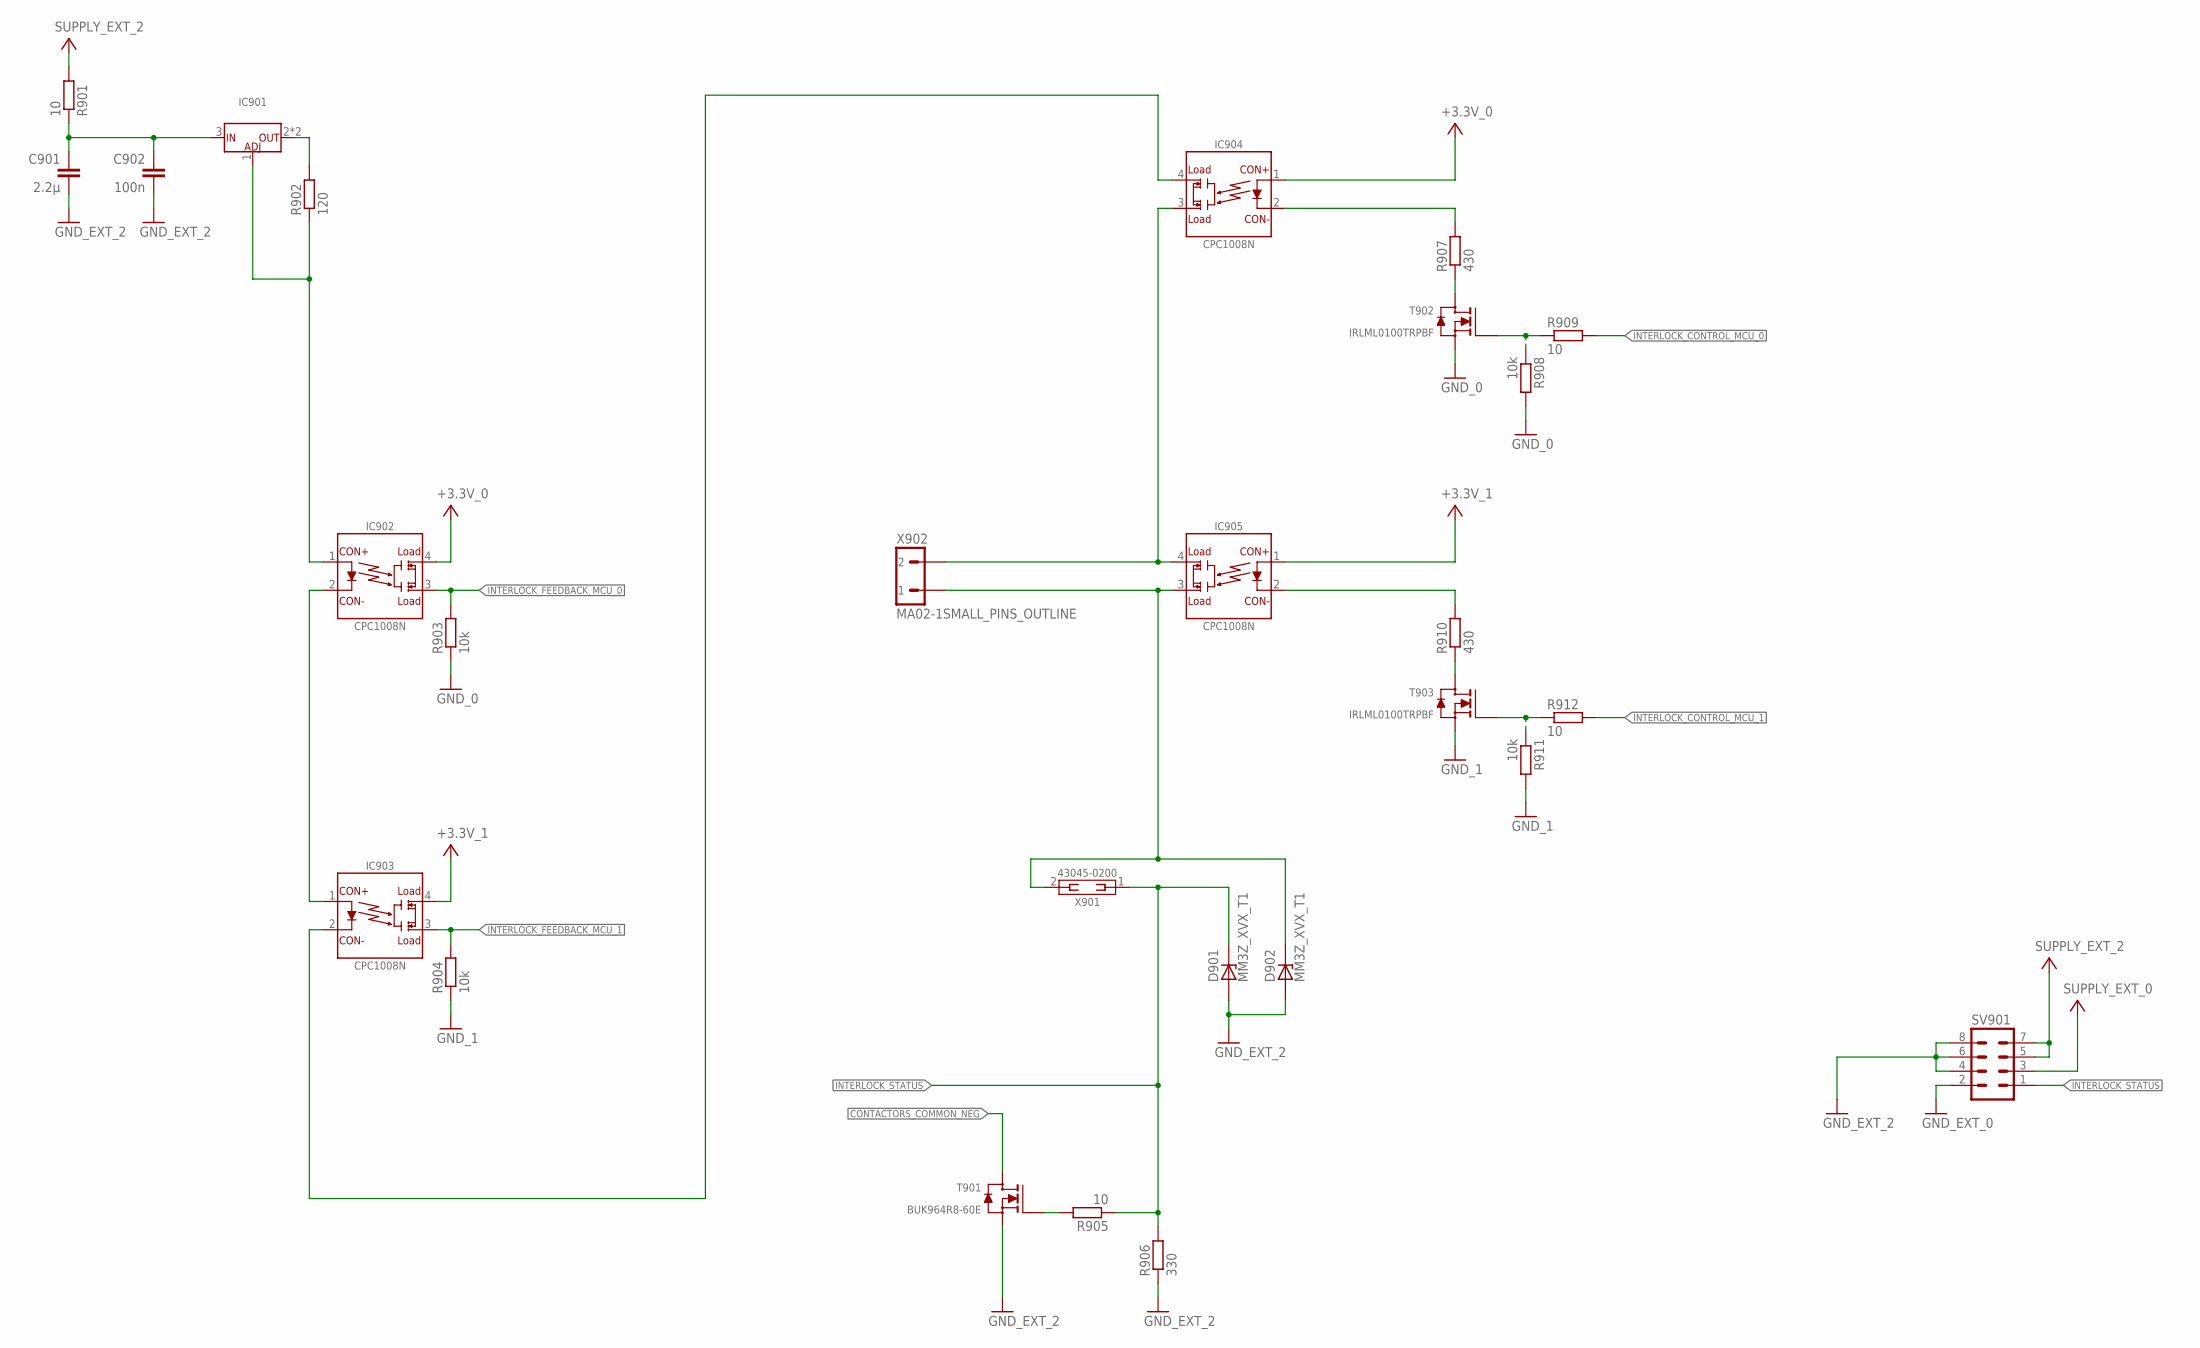
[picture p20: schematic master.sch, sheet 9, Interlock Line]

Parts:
C901: 2.2µ; C0805
C902: 100n; C0603
D901, D902: MM3Z_XVX_T1; SOD323
IC901: LM317MBSTT3G; IC_SMD_SOT-223_(TO-261)_(CASE318E-04)_R_REV01
IC902, IC903, IC904, IC905: CPC1008N; K_SMD_SOP-4_R_IXYS_REV01
R901, R905, R909, R912: 10; R0603
R902: 120; R0603
R903, R904, R908, R911: 10k; R0603
R906: 330; R0603
R907, R910: 430; R0603
SV901: MA04-2
T901: BUK964R8-60E; V_SMD_TO-263_(D²PAK)_R_NXP_REV01
T902, T903: IRLML0100TRPBF; V_SMD_SOT-23_(TO-236AB)_R_IR_REV01
X901: 43045-0200_MOLEX_2PIN; X_TH_MOLEX_43045-0200_R_REV01
X902: MA02-1SMALL_PINS_OUTLINE; MA02-1A

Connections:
+3.3V_0: IC902.4, IC904.1 (CON+); also elsewhere on the board
+3.3V_1: IC903.4, IC905.1 (CON+); also elsewhere on the board
CONTACTORS_COMMON_NEG: T901.2 (D); also elsewhere on the board
GND_0: R903.1, R908.2, T902.2 (S); also elsewhere on the board
GND_1: R904.1, R911.2, T903.2 (S); also elsewhere on the board
GND_EXT_0: SV901.2; also elsewhere on the board
GND_EXT_2: C901.2, C902.2, D901.A, D902.A, R906.1, SV901.4, SV901.6, SV901.8, T901.3 (S); also elsewhere on the board
INTERLOCK_CONTROL_MCU_0: R909.2; also elsewhere on the board
INTERLOCK_CONTROL_MCU_1: R912.2; also elsewhere on the board
INTERLOCK_FEEDBACK_MCU_0: IC902.3, R903.2; also elsewhere on the board
INTERLOCK_FEEDBACK_MCU_1: IC903.3, R904.2; also elsewhere on the board
INTERLOCK_STATUS: D901.C (K), R905.1, R906.2, SV901.1, X901.1
unnamed: R905.2, T901.1 (G)
unnamed: D902.C (K), IC905.3, X901.2, X902.1
unnamed: R907.1, T902.3 (D)
unnamed: R910.1, T903.3 (D)
unnamed: C901.1, C902.1, IC901.3 (IN), R901.1
unnamed: IC901.2 (OUT), IC901.4 (OUT), R902.2
unnamed: IC901.1 (ADJ), IC902.1 (CON+), R902.1
unnamed: IC902.2 (CON-), IC903.1 (CON+)
unnamed: IC905.2 (CON-), R910.2
unnamed: R911.1, R912.1, T903.1 (G)
unnamed: IC903.2 (CON-), IC904.4
unnamed: IC904.2 (CON-), R907.2
unnamed: R908.1, R909.1, T902.1 (G)
unnamed: IC904.3, IC905.4, X902.2
SUPPLY_EXT_0: SV901.3; also elsewhere on the board
SUPPLY_EXT_2: R901.2, SV901.5, SV901.7; also elsewhere on the board

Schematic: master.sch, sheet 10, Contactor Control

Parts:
D1001, D1002, D1003, D1004, D1005, D1006: GF1; SMA-DO214AC
F1001, F1002, F1003, F1004, F1005, F1006: 4,00A_UMT; F_SMD_11,00MMX3,00MMX3,00MM_(UMT)_R_SCHURTER_REV01
IC1001, IC1002, IC1003, IC1004, IC1005, IC1006: AQV252G2S; K_SMD_SOP-6_R_PANASONIC_REV01
R1001, R1002, R1007, R1008, R1013, R1014: 10; R0603
R1003, R1004, R1009, R1010, R1015, R1016: 10k; R0603
R1005, R1006, R1011, R1012, R1017, R1018: 430; R0603
T1001, T1002, T1003, T1004, T1005, T1006: IRLML0100TRPBF; V_SMD_SOT-23_(TO-236AB)_R_IR_REV01

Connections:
+3.3V_0: IC1001.1, IC1002.1, IC1003.1, IC1004.1, IC1005.1, IC1006.1; also elsewhere on the board
CONTACTORS_COMMON_NEG: D1001.A, D1002.A, D1003.A, D1004.A, D1005.A, D1006.A; also elsewhere on the board
CONTACTOR_0_COIL_POS: D1001.K (C), F1001.2; also elsewhere on the board
CONTACTOR_0_CONTROL: R1001.2; also elsewhere on the board
CONTACTOR_1_COIL_POS: D1003.K (C), F1003.2; also elsewhere on the board
CONTACTOR_1_CONTROL: R1007.2; also elsewhere on the board
CONTACTOR_2_COIL_POS: D1005.K (C), F1005.2; also elsewhere on the board
CONTACTOR_2_CONTROL: R1013.2; also elsewhere on the board
CONTACTOR_3_COIL_POS: D1002.K (C), F1002.2; also elsewhere on the board
CONTACTOR_3_CONTROL: R1002.2; also elsewhere on the board
CONTACTOR_4_COIL_POS: D1004.K (C), F1004.2; also elsewhere on the board
CONTACTOR_4_CONTROL: R1008.2; also elsewhere on the board
CONTACTOR_5_COIL_POS: D1006.K (C), F1006.2; also elsewhere on the board
CONTACTOR_5_CONTROL: R1014.2; also elsewhere on the board
GND_0: R1003.1, R1004.1, R1009.1, R1010.1, R1015.1, R1016.1, T1001.2 (S), T1002.2 (S), T1003.2 (S), T1004.2 (S), T1005.2 (S), T1006.2 (S); also elsewhere on the board
unnamed: IC1002.2, R1006.2
unnamed: R1006.1, T1002.3 (D)
unnamed: IC1001.2, R1005.2
unnamed: R1005.1, T1001.3 (D)
unnamed: R1011.1, T1003.3 (D)
unnamed: IC1003.2, R1011.2
unnamed: IC1004.2, R1012.2
unnamed: R1012.1, T1004.3 (D)
unnamed: IC1005.2, R1017.2
unnamed: R1017.1, T1005.3 (D)
unnamed: IC1006.2, R1018.2
unnamed: R1018.1, T1006.3 (D)
unnamed: F1001.1, IC1001.5
unnamed: F1003.1, IC1003.5
unnamed: F1004.1, IC1004.5
unnamed: F1005.1, IC1005.5
unnamed: F1002.1, IC1002.5
unnamed: F1006.1, IC1006.5
unnamed: R1007.1, R1009.2, T1003.1 (G)
unnamed: R1001.1, R1003.2, T1001.1 (G)
unnamed: R1013.1, R1015.2, T1005.1 (G)
unnamed: R1002.1, R1004.2, T1002.1 (G)
unnamed: R1008.1, R1010.2, T1004.1 (G)
unnamed: R1014.1, R1016.2, T1006.1 (G)
SUPPLY_EXT_2: IC1001.4, IC1001.6, IC1002.4, IC1002.6, IC1003.4, IC1003.6, IC1004.4, IC1004.6, IC1005.4, IC1005.6, IC1006.4, IC1006.6; also elsewhere on the board

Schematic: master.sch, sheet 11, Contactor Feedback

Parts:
C1101: 1µ; C0603
C1102, C1103, C1104, C1105, C1106, C1107: 100n; C0603
D1101, D1102, D1103, D1104, D1105, D1106: CDSOD323-T05; D_SMD_SOD323_(SC-76)_R_BOURNS_REV01
IC1101: UA78L05ACPK; IC_SMD_SOT-89_(SC-62/TO-243)_(R-PSSO-F3)_R_TI_REV01
IC1102, IC1103: ADUM3300ARW; IC_SMD_SOIC-16_(JEDEC_MS-013-AA)_R_ANALOG_REV01
R1101, R1102, R1103, R1104, R1105, R1106: 47; R0603
R1107, R1108, R1109, R1110, R1111, R1112: 10k; R0603

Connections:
+3.3V_0: C1106.1, C1107.1, IC1102.10 (VE2), IC1102.16 (VDD2), IC1103.10 (VE2), IC1103.16 (VDD2); also elsewhere on the board
CONTACTOR_0_FEEDBACK: IC1102.14 (VOA); also elsewhere on the board
CONTACTOR_0_FEEDBACK_EXT: R1101.1; also elsewhere on the board
CONTACTOR_1_FEEDBACK: IC1102.13 (VOB); also elsewhere on the board
CONTACTOR_1_FEEDBACK_EXT: R1102.1; also elsewhere on the board
CONTACTOR_2_FEEDBACK: IC1102.12 (VOC); also elsewhere on the board
CONTACTOR_2_FEEDBACK_EXT: R1103.1; also elsewhere on the board
CONTACTOR_3_FEEDBACK: IC1103.14 (VOA); also elsewhere on the board
CONTACTOR_3_FEEDBACK_EXT: R1104.2; also elsewhere on the board
CONTACTOR_4_FEEDBACK: IC1103.13 (VOB); also elsewhere on the board
CONTACTOR_4_FEEDBACK_EXT: R1105.2; also elsewhere on the board
CONTACTOR_5_FEEDBACK: IC1103.12 (VOC); also elsewhere on the board
CONTACTOR_5_FEEDBACK_EXT: R1106.2; also elsewhere on the board
CONTACTOR_FEEDBACK_SUPPLY_EXT: C1103.1, C1104.1, C1105.1, IC1101.1 (OUT), IC1102.1 (VDD1), IC1103.1 (VDD1), R1107.2, R1108.2, R1109.2, R1110.2, R1111.2, R1112.2
GND_0: C1106.2, C1107.2, IC1102.9 (GND2), IC1102.15 (GND2), IC1103.9 (GND2), IC1103.15 (GND2); also elsewhere on the board
GND_EXT_0: C1101.2, C1102.2, C1103.2, C1104.2, C1105.2, D1101.A, D1102.A, D1103.A, D1104.A, D1105.A, D1106.A, IC1101.2 (COM), IC1102.2 (GND1), IC1102.8 (GND1), IC1103.2 (GND1), IC1103.8 (GND1); also elsewhere on the board
unnamed: D1101.C, IC1102.3 (VIA), R1101.2, R1107.1
unnamed: D1103.C, IC1102.4 (VIB), R1102.2, R1109.1
unnamed: D1105.C, IC1102.5 (VIC), R1103.2, R1111.1
unnamed: D1102.C, IC1103.3 (VIA), R1104.1, R1108.1
unnamed: D1104.C, IC1103.4 (VIB), R1105.1, R1110.1
unnamed: D1106.C, IC1103.5 (VIC), R1106.1, R1112.1
SUPPLY_EXT_0: C1101.1, C1102.1, IC1101.3 (IN); also elsewhere on the board

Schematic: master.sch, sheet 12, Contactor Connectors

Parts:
X1201, X1202, X1203, X1204, X1205, X1206: 43045-0400_MOLEX_4PIN; X_TH_MOLEX_43045-0400_R_REV01

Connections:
CONTACTORS_COMMON_NEG: X1201.4, X1202.4, X1203.4, X1204.4, X1205.4, X1206.4; also elsewhere on the board
CONTACTOR_0_COIL_POS: X1201.3; also elsewhere on the board
CONTACTOR_0_FEEDBACK_EXT: X1201.2; also elsewhere on the board
CONTACTOR_1_COIL_POS: X1203.3; also elsewhere on the board
CONTACTOR_1_FEEDBACK_EXT: X1203.2; also elsewhere on the board
CONTACTOR_2_COIL_POS: X1205.3; also elsewhere on the board
CONTACTOR_2_FEEDBACK_EXT: X1205.2; also elsewhere on the board
CONTACTOR_3_COIL_POS: X1202.3; also elsewhere on the board
CONTACTOR_3_FEEDBACK_EXT: X1202.2; also elsewhere on the board
CONTACTOR_4_COIL_POS: X1204.3; also elsewhere on the board
CONTACTOR_4_FEEDBACK_EXT: X1204.2; also elsewhere on the board
CONTACTOR_5_COIL_POS: X1206.3; also elsewhere on the board
CONTACTOR_5_FEEDBACK_EXT: X1206.2; also elsewhere on the board
GND_EXT_0: X1201.1, X1202.1, X1203.1, X1204.1, X1205.1, X1206.1; also elsewhere on the board

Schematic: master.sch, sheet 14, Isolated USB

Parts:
C1401, C1406: 4.7µ; C0603
C1402, C1403, C1404, C1405, C1407, C1408, C1409, C1410: 100n; C0603
IC1401, IC1404: IP4220CZ6; D_SMD_TSOP6_(SOT457/SC-74)_R_NXP_REV01
IC1402, IC1405: FT231XS-R; IC_SMD_SSOP-20_R_FTDI_REV01
IC1403, IC1406: ADUM3401ARW; IC_SMD_SOIC-16_(JEDEC_MS-013-AA)_R_ANALOG_REV01
R1401, R1402, R1405, R1406: 27; 0603
R1403, R1404, R1407, R1408: 0; 0603
X1401, X1402: MINI-USB-2.0; X_SMD_MINI-USB-2.0-TYPAB_R_MULTICOMP_REV01

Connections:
+3.3V_0: C1405.1, IC1403.10 (VE2), IC1403.16 (VDD2); also elsewhere on the board
+3.3V_1: C1410.1, IC1406.10 (VE2), IC1406.16 (VDD2); also elsewhere on the board
DM: IC1401.4 (I/O3), R1401.2, X1401.2
DM1: IC1404.4 (I/O3), R1405.2, X1402.2
DP: IC1401.6 (I/O4), R1402.2, X1401.3
DP1: IC1404.6 (I/O4), R1406.2, X1402.3
FTDI_MCU_0_DTR: IC1403.13 (VOB); also elsewhere on the board
FTDI_MCU_0_RTS: IC1403.14 (VOA); also elsewhere on the board
FTDI_MCU_0_RX: IC1403.12 (VOC); also elsewhere on the board
FTDI_MCU_0_TX: IC1403.11 (VID); also elsewhere on the board
FTDI_MCU_1_DTR: IC1406.13 (VOB); also elsewhere on the board
FTDI_MCU_1_RTS: IC1406.14 (VOA); also elsewhere on the board
FTDI_MCU_1_RX: IC1406.12 (VOC); also elsewhere on the board
FTDI_MCU_1_TX: IC1406.11 (VID); also elsewhere on the board
GND_0: C1405.2, IC1403.9 (GND2), IC1403.15 (GND2); also elsewhere on the board
GND_1: C1410.2, IC1406.9 (GND2), IC1406.15 (GND2); also elsewhere on the board
unnamed: IC1402.11 (USBDP), R1402.1
unnamed: IC1402.12 (USBDM), R1401.1
unnamed: IC1405.11 (USBDP), R1406.1
unnamed: IC1405.12 (USBDM), R1405.1
unnamed: IC1402.20 (TXD), IC1403.5 (VIC)
unnamed: IC1405.20 (TXD), IC1406.5 (VIC)
unnamed: IC1405.4 (RXD), IC1406.6 (VOD)
unnamed: IC1405.2 (RTS#), IC1406.3 (VIA)
unnamed: IC1405.1 (DTR#), IC1406.4 (VIB)
unnamed: IC1402.4 (RXD), IC1403.6 (VOD)
unnamed: IC1402.1 (DTR#), IC1403.4 (VIB)
unnamed: C1409.1, IC1405.3 (VCCIO), IC1405.13 (3V3OUT), IC1405.14 (RESET#)
unnamed: IC1405.9 (CTS#), R1407.1
unnamed: IC1402.2 (RTS#), IC1403.3 (VIA)
unnamed: IC1405.7 (DSR#), R1408.1
unnamed: IC1402.9 (CTS#), R1403.1
unnamed: IC1402.7 (DSR#), R1404.1
USB_0_GND_EXT: C1401.2, C1402.2, C1403.2, C1404.2, IC1401.2 (GND), IC1402.6 (GND1), IC1402.16 (GND2), IC1403.2 (GND1), IC1403.8 (GND1), R1403.2, R1404.2, X1401.5
USB_0_VBUS1_EXT: C1401.1, C1402.1, C1403.1, IC1401.5 (VP), IC1402.15 (VCC), IC1403.1 (VDD1), IC1403.7 (VE1), X1401.1
USB_0_VCC_EXT: C1404.1, IC1402.3 (VCCIO), IC1402.13 (3V3OUT), IC1402.14 (RESET#)
USB_GND_0_EXT1: C1406.2, C1407.2, C1408.2, C1409.2, IC1404.2 (GND), IC1405.6 (GND1), IC1405.16 (GND2), IC1406.2 (GND1), IC1406.8 (GND1), R1407.2, R1408.2, X1402.5
USB_VBUS1_0_EXT1: C1406.1, C1407.1, C1408.1, IC1404.5 (VP), IC1405.15 (VCC), IC1406.1 (VDD1), IC1406.7 (VE1), X1402.1

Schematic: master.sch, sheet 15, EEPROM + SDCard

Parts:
C1501: 100n; 0603
IC1501: AT25128B-SSHL-T; IC_SMD_SOIC-8_R_ATMEL_REV01
R1501, R1502: 10k; 0603

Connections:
+3.3V_0: C1501.2, IC1501.8 (VCC), R1501.2, R1502.2; also elsewhere on the board
DATA_STORAGE_SPI_EEPROM_CS: IC1501.1 (!CS); also elsewhere on the board
DATA_STORAGE_SPI_MISO: IC1501.2 (SO); also elsewhere on the board
DATA_STORAGE_SPI_MOSI: IC1501.5 (SI); also elsewhere on the board
DATA_STORAGE_SPI_SCK: IC1501.6 (SCK); also elsewhere on the board
GND_0: C1501.1, IC1501.4 (GND); also elsewhere on the board
unnamed: IC1501.7 (HOLD), R1501.1
unnamed: IC1501.3 (!WP), R1502.1

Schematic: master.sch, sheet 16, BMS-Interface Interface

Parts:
C1601, C1602, C1603, C1604: 100n; C0603
SV1601, SV1603: MA04-2
SV1602, SV1604: MA08-2
X1601: 43045-1600_MOLEX_16PIN; X_TH_MOLEX_43045-1600_R_REV01

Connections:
+3.3V_0: C1601.1, SV1602.3; also elsewhere on the board
+3.3V_1: C1603.1, SV1604.3; also elsewhere on the board
+5.0V_0: C1602.1, SV1602.4; also elsewhere on the board
+5.0V_1: C1604.1, SV1604.4; also elsewhere on the board
BMS-INTERFACE_0_GPIO_0: SV1602.11; also elsewhere on the board
BMS-INTERFACE_0_GPIO_1: SV1602.12; also elsewhere on the board
BMS-INTERFACE_0_GPIO_2: SV1602.2; also elsewhere on the board
BMS-INTERFACE_0_GPIO_3: SV1602.1; also elsewhere on the board
BMS-INTERFACE_0_SPI_CS: SV1602.8; also elsewhere on the board
BMS-INTERFACE_0_SPI_MISO: SV1602.6; also elsewhere on the board
BMS-INTERFACE_0_SPI_MOSI: SV1602.5; also elsewhere on the board
BMS-INTERFACE_0_SPI_SCK: SV1602.7; also elsewhere on the board
BMS-INTERFACE_1_GPIO_0: SV1604.11; also elsewhere on the board
BMS-INTERFACE_1_GPIO_1: SV1604.12; also elsewhere on the board
BMS-INTERFACE_1_GPIO_2: SV1604.2; also elsewhere on the board
BMS-INTERFACE_1_GPIO_3: SV1604.1; also elsewhere on the board
BMS-INTERFACE_1_SPI_CS: SV1604.8; also elsewhere on the board
BMS-INTERFACE_1_SPI_MISO: SV1604.6; also elsewhere on the board
BMS-INTERFACE_1_SPI_MOSI: SV1604.5; also elsewhere on the board
BMS-INTERFACE_1_SPI_SCK: SV1604.7; also elsewhere on the board
GND_0: C1601.2, C1602.2, SV1602.9, SV1602.10; also elsewhere on the board
GND_1: C1603.2, C1604.2, SV1604.9, SV1604.10; also elsewhere on the board
unnamed: SV1601.1, X1601.1
unnamed: SV1601.2, X1601.9
unnamed: SV1601.3, X1601.2
unnamed: SV1601.4, X1601.10
unnamed: SV1601.5, X1601.3
unnamed: SV1601.6, X1601.11
unnamed: SV1601.7, X1601.4
unnamed: SV1601.8, X1601.12
unnamed: SV1603.1, X1601.5
unnamed: SV1603.3, X1601.6
unnamed: SV1603.5, X1601.7
unnamed: SV1603.7, X1601.8
unnamed: SV1603.2, X1601.13
unnamed: SV1603.4, X1601.14
unnamed: SV1603.6, X1601.15
unnamed: SV1603.8, X1601.16

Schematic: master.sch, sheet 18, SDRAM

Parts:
C1801, C1802, C1803, C1804, C1805, C1806, C1807: 100n; C0603
IC1801: IS42S16400J-5TL; IC_SMD_TSOP-II_(54-PIN)_R_ISSI_REV01

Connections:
+3.3V_0: C1801.1, C1802.1, C1803.1, C1804.1, C1805.1, C1806.1, C1807.1, IC1801.1 (VDD), IC1801.3 (VDDQ), IC1801.9 (VDDQ), IC1801.14 (VDD), IC1801.27 (VDD), IC1801.43 (VDDQ), IC1801.49 (VDDQ); also elsewhere on the board
FMC_MCU_0_RAM_A0: IC1801.23 (A0); also elsewhere on the board
FMC_MCU_0_RAM_A1: IC1801.24 (A1); also elsewhere on the board
FMC_MCU_0_RAM_A2: IC1801.25 (A2); also elsewhere on the board
FMC_MCU_0_RAM_A3: IC1801.26 (A3); also elsewhere on the board
FMC_MCU_0_RAM_A4: IC1801.29 (A4); also elsewhere on the board
FMC_MCU_0_RAM_A5: IC1801.30 (A5); also elsewhere on the board
FMC_MCU_0_RAM_A6: IC1801.31 (A6); also elsewhere on the board
FMC_MCU_0_RAM_A7: IC1801.32 (A7); also elsewhere on the board
FMC_MCU_0_RAM_A8: IC1801.33 (A8); also elsewhere on the board
FMC_MCU_0_RAM_A9: IC1801.34 (A9); also elsewhere on the board
FMC_MCU_0_RAM_A10: IC1801.22 (A10); also elsewhere on the board
FMC_MCU_0_RAM_A11: IC1801.35 (A11); also elsewhere on the board
FMC_MCU_0_RAM_BA0: IC1801.20 (BA0); also elsewhere on the board
FMC_MCU_0_RAM_BA1: IC1801.21 (BA1); also elsewhere on the board
FMC_MCU_0_RAM_D0: IC1801.2 (DQ0); also elsewhere on the board
FMC_MCU_0_RAM_D1: IC1801.4 (DQ1); also elsewhere on the board
FMC_MCU_0_RAM_D2: IC1801.5 (DQ2); also elsewhere on the board
FMC_MCU_0_RAM_D3: IC1801.7 (DQ3); also elsewhere on the board
FMC_MCU_0_RAM_D4: IC1801.8 (DQ4); also elsewhere on the board
FMC_MCU_0_RAM_D5: IC1801.10 (DQ5); also elsewhere on the board
FMC_MCU_0_RAM_D6: IC1801.11 (DQ6); also elsewhere on the board
FMC_MCU_0_RAM_D7: IC1801.13 (DQ7); also elsewhere on the board
FMC_MCU_0_RAM_D8: IC1801.42 (DQ8); also elsewhere on the board
FMC_MCU_0_RAM_D9: IC1801.44 (DQ9); also elsewhere on the board
FMC_MCU_0_RAM_D10: IC1801.45 (DQ10); also elsewhere on the board
FMC_MCU_0_RAM_D11: IC1801.47 (DQ11); also elsewhere on the board
FMC_MCU_0_RAM_D12: IC1801.48 (DQ12); also elsewhere on the board
FMC_MCU_0_RAM_D13: IC1801.50 (DQ13); also elsewhere on the board
FMC_MCU_0_RAM_D14: IC1801.51 (DQ14); also elsewhere on the board
FMC_MCU_0_RAM_D15: IC1801.53 (DQ15); also elsewhere on the board
FMC_MCU_0_RAM_NBL0: IC1801.15 (LDQM); also elsewhere on the board
FMC_MCU_0_RAM_NBL1: IC1801.39 (UDQM); also elsewhere on the board
FMC_MCU_0_RAM_SDCKE1: IC1801.37 (CKE); also elsewhere on the board
FMC_MCU_0_RAM_SDCLK: IC1801.38 (CLK); also elsewhere on the board
FMC_MCU_0_RAM_SDNCAS: IC1801.17 (!CAS); also elsewhere on the board
FMC_MCU_0_RAM_SDNE1: IC1801.19 (!CS); also elsewhere on the board
FMC_MCU_0_RAM_SDNRAS: IC1801.18 (!RAS); also elsewhere on the board
FMC_MCU_0_RAM_SDNWE: IC1801.16 (!WE); also elsewhere on the board
GND_0: C1801.2, C1802.2, C1803.2, C1804.2, C1805.2, C1806.2, C1807.2, IC1801.6 (GNDQ), IC1801.12 (GNDQ), IC1801.28 (GND), IC1801.41 (GND), IC1801.46 (GNDQ), IC1801.52 (GNDQ), IC1801.54 (GND); also elsewhere on the board

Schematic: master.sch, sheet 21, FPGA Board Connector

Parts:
C2101, C2102: 100n; C0603
SV2101: MA04-2

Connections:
+3.3V_0: C2101.2, SV2101.1; also elsewhere on the board
+5.0V_0: C2102.1, SV2101.2; also elsewhere on the board
GND_0: C2101.1, C2102.2, SV2101.5, SV2101.6; also elsewhere on the board
MCU_TO_FPGA_INTERFACE_MCU_0_CS: SV2101.8; also elsewhere on the board
MCU_TO_FPGA_INTERFACE_MCU_0_MISO: SV2101.3; also elsewhere on the board
MCU_TO_FPGA_INTERFACE_MCU_0_MOSI: SV2101.7; also elsewhere on the board
MCU_TO_FPGA_INTERFACE_MCU_0_SCK: SV2101.4; also elsewhere on the board

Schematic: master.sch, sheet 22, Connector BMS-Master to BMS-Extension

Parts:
JP2201, JP2202: PINHD-2X12; 2X12

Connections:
+3.3V_0: JP2201.1, JP2201.3, JP2202.1, JP2202.3; also elsewhere on the board
ADC_MCU_0_CH_0: JP2202.8; also elsewhere on the board
ADC_MCU_0_CH_1: JP2202.7; also elsewhere on the board
ADC_MCU_0_CH_2: JP2202.6; also elsewhere on the board
ADC_MCU_0_CH_3: JP2202.5; also elsewhere on the board
ADC_MCU_0_CH_4: JP2202.9; also elsewhere on the board
CAN_1_RX: JP2201.6; also elsewhere on the board
CAN_1_TRANS_STANDBY_CONTROL: JP2201.5; also elsewhere on the board
CAN_1_TX: JP2201.7; also elsewhere on the board
CONTACTOR_6_CONTROL: JP2201.18; also elsewhere on the board
CONTACTOR_6_FEEDBACK: JP2201.17; also elsewhere on the board
CONTACTOR_7_CONTROL: JP2201.16; also elsewhere on the board
CONTACTOR_7_FEEDBACK: JP2201.15; also elsewhere on the board
CONTACTOR_8_CONTROL: JP2202.10; also elsewhere on the board
CONTACTOR_8_FEEDBACK: JP2202.11; also elsewhere on the board
DATA_STORAGE_SPI_MISO: JP2201.21; also elsewhere on the board
DATA_STORAGE_SPI_MOSI: JP2201.19; also elsewhere on the board
DATA_STORAGE_SPI_SCK: JP2201.20; also elsewhere on the board
DATA_STORAGE_SPI_SDCARD_NSS: JP2201.23; also elsewhere on the board
GND_0: JP2201.2, JP2201.4, JP2202.2, JP2202.4; also elsewhere on the board
ISONOC_0_CONTROL: JP2202.16; also elsewhere on the board
ISONOC_1_CONTROL: JP2202.17; also elsewhere on the board
ISONOC_2_CONTROL: JP2202.18; also elsewhere on the board
ISONOC_3_CONTROL: JP2202.19; also elsewhere on the board
ISONOC_4_CONTROL: JP2202.20; also elsewhere on the board
ISONOC_5_CONTROL: JP2202.21; also elsewhere on the board
ISO_GPIO_MCU_0_IN_0: JP2202.22; also elsewhere on the board
ISO_GPIO_MCU_0_IN_1: JP2202.23; also elsewhere on the board
ISO_GPIO_MCU_0_IN_2: JP2201.13; also elsewhere on the board
ISO_GPIO_MCU_0_IN_3: JP2201.10; also elsewhere on the board
ISO_GPIO_MCU_0_OUT_0: JP2201.9; also elsewhere on the board
ISO_GPIO_MCU_0_OUT_1: JP2201.14; also elsewhere on the board
ISO_GPIO_MCU_0_OUT_2: JP2201.11; also elsewhere on the board
ISO_GPIO_MCU_0_OUT_3: JP2201.12; also elsewhere on the board
RS485_MCU_0_DE: JP2202.15; also elsewhere on the board
RS485_MCU_0_NRE: JP2202.14; also elsewhere on the board
RS485_MCU_0_RX: JP2202.13; also elsewhere on the board
RS485_MCU_0_TX: JP2202.12; also elsewhere on the board
SDCARD_SUPPLY_CONTROL: JP2201.22; also elsewhere on the board

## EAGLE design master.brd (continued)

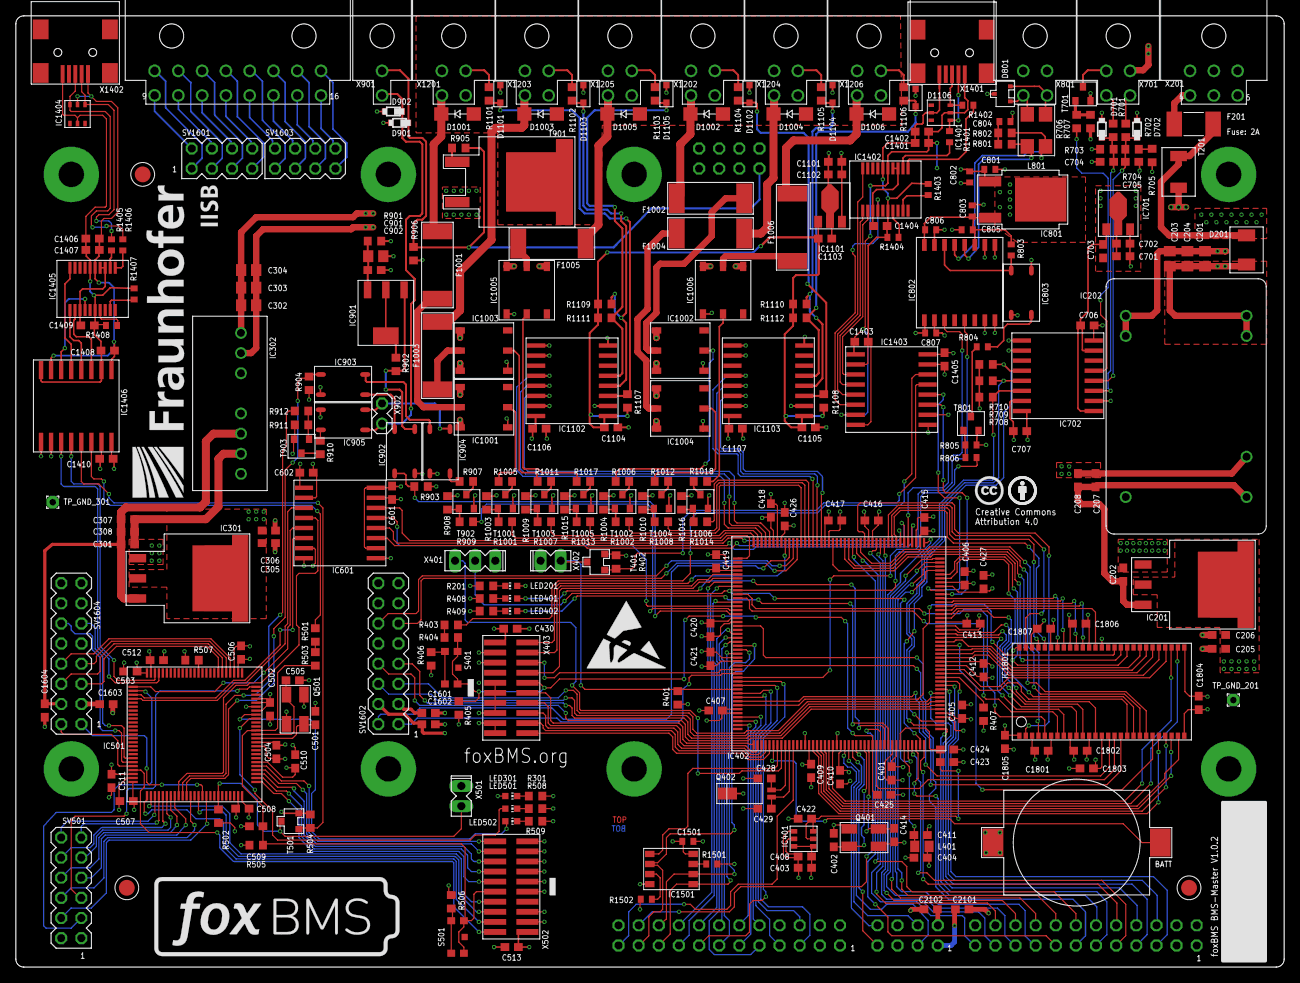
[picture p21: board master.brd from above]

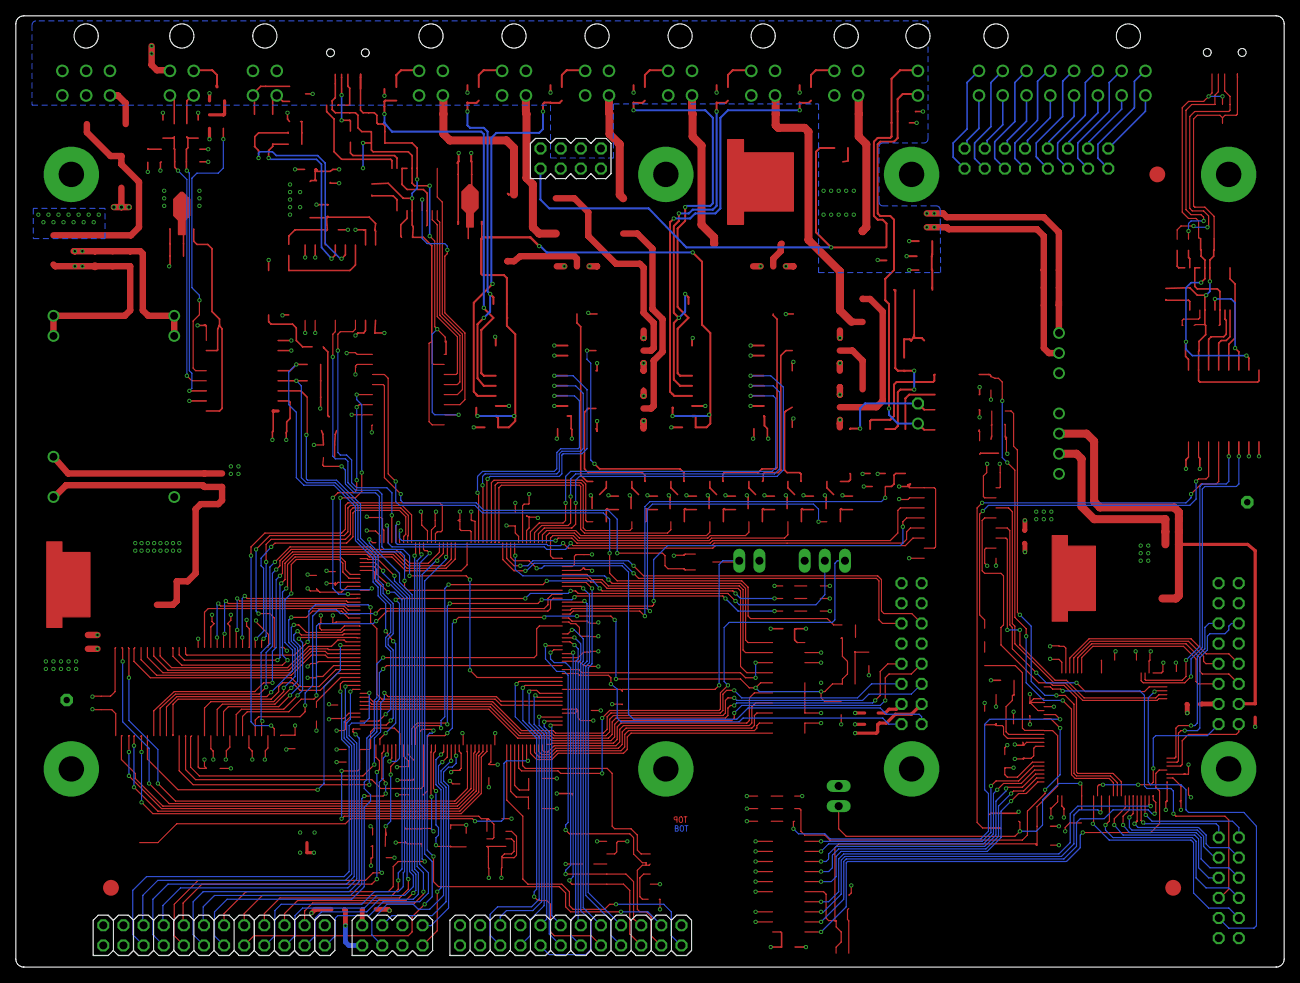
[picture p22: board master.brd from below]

Board: 4 copper layers, 160.0 x 120.0 mm, 318 parts (4 on the bottom side), 331 nets.

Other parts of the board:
U$1, U$3, U$4: FIDUCIAL_1MM
U$2: ESD_10.00

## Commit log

2017-12-13 Initial commit of the hardware design resources for the foxBMS Master board
    [master.brd, master.sch, master_bom.xlsx]
2017-12-13 fixed fuse value in schematic
    [master.brd, master.sch]

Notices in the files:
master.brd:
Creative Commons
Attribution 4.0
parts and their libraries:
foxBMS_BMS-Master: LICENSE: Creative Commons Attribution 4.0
